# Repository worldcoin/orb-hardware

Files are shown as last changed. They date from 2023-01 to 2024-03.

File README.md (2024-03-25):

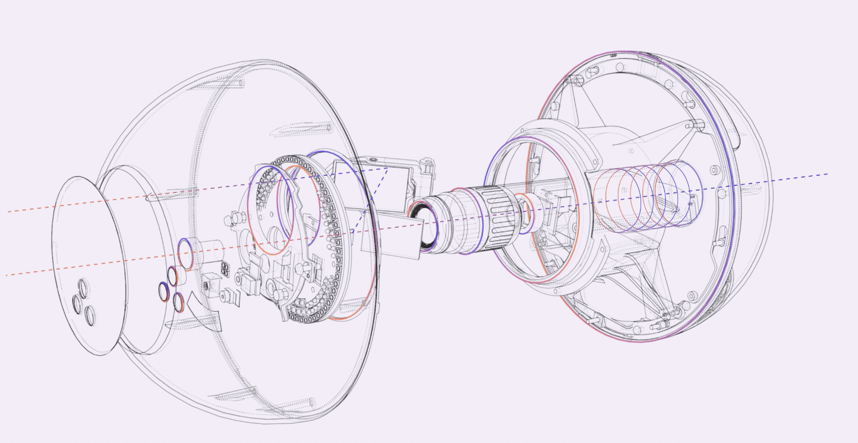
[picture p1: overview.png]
Overview


# Worldcoin Hardware

As we work towards decentralization, we are incrementally open sourcing the Orb. The goal is to provide transparency and, eventually, the ability to verify our claims. Ultimately, we plan to decentralize everything involving the Orb, enabling others to develop, manufacture, and operate similar devices to issue Proof-of-Personhood credentials in a privacy-preserving manner. 

We're excited to share the engineering files of the Orb with you! For more details on how it works in detail check out [our blogpost](https://worldcoin.org/blog/engineering/opening-orb-look-inside-worldcoin-biometric-imaging-device).

If you see any issues with the design, we encourage you to create an issue to help improve future versions. 

## High-level Goals

The goal of the hardware team at Tools for Humanity is to provide products that on a high level meet the following requirements:

* Validate humanness & create a unique code to verify uniqueness in a privacy-preserving manner, as seamlessly as possible
* Ready for mobile and outdoor use (think camera equipment)
* Continuous mobile use throughout the day without significant downtime
* Enable detection of internal attacks (physical manipulation of the device) and external fraud attempts (presentation attacks) by using additional sensors that are not needed for the calculation of the unique code
* Unique visual appearance

## Hardware Products

Our initial hardware product release consists of: 

* The Orb: our core imaging device
* A custom exchangeable battery for the Orb

We will expand the scope of this repository as new products mature. We expect privacy-preserving Proof-of-Personhood to become a lasting primitive for the internet.

## Directory Structure

    ├── Orb
    │   ├── Electronics
    │   ├── Mechanics
    |   └── BOM
    |
    ├── Battery
    |   ├── Electronics
    │   ├── Mechanics
    |   └── BOM

## What's not included

### Tamper detection system not disclosed 

For obvious reasons, these files do not include the PCBs and sensors related to the Orb's tamper detection system. 

### Components pending licenses for disclosure

When designing our product, we have utilized certain proprietary information (IP) that we have not yet received confirmation from the vendor to share, or that cannot be shared as part of our open-source efforts. This includes CAD models of certain electronic boards and IP related to the electrical interface between the Jetson and the heat camera. As a result, we are currently unable to publish the bridge board that connects the main board and the front unit.

## License

Copyright 2020-2023 The Worldcoin Foundation.

You may use this package under the Worldcoin Responsible Use License, version 1.0, or at your option, any later version. See the file [COPYING](COPYING.md) for more details, and [LICENSE](LICENSE.md) for the terms of the Worldcoin Responsible Use License, version 1.0.

The Worldcoin Responsible Use License seeks a balance between fostering transparency and decentralization while preventing capture (inspired by Uniswaps [BSL](https://uniswapfoundation.mirror.xyz/lr8hUW5FFYWmvsm9ZmO6bLdLAaAx5EAnFEbJG_OTd8g) and Electric Coin Co.’s [BOSL](https://electriccoin.co/blog/introducing-tgppl-a-radically-new-type-of-open-source-license/)) and reducing the risk that Worldcoin technology could be used in harmful ways. Under the license, within about two years of publication the Worldcoin Foundation will - consistent with its governance protocols and practices at the time - review and decide whether to remove the use restrictions specified in Section II.1 of the license. Further, no more than two years after that review date, those restrictions will be lifted. As this is an unfamiliar license you may have questions or feedback. Any proposals for improvements, objections or alternative approaches are welcome.

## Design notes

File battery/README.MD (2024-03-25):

## Overview
Our exchangeable battery is responsible for powering the orb during the dayli operations. Key facts: 
* **Cell**: 8x 18650 Li-Ion cells 
* **Configuration**: 4SP2 (4 in series, 2 strings parallel)
* **Nominal voltage**: 14.8V
* **Capacity**: 96.48Wh
* **Charging interface**: USB-C
* **Other**: UN38.3 certified

## Mechanics

You can download the .stp-files [here](mechanics/download.sh).

Preview STP-File:
<p align="center">
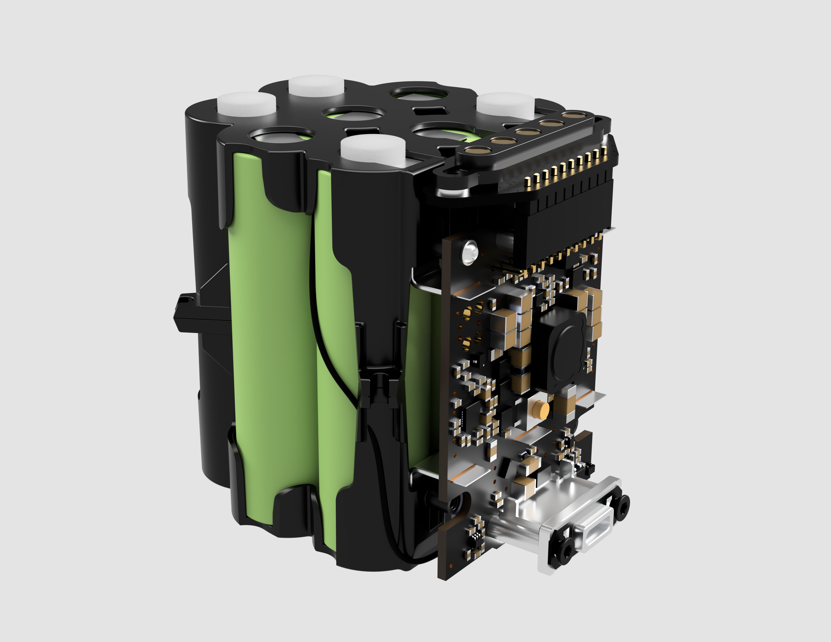
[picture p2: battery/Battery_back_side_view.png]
    
</p>

## Electronics

Preview battery circuit board:

<p align="center">
    
</p>

## Bill of material structure
Part of our release is a drilled-down bill of material listing all the parts used in our device. 

The columns in that file are: 
* **Level**: Due to multiple assemblies in our device, we have a nested BOM. The level column tells you how deep this component is nested.
* **Item number**: Running number within the Assembly / Sub-Assembly
* **Partnumber**: Our internal part-number
* **Manufacturer P/N**: The part-number / unique name that our supplier uses as a part reference
* **Quantity**: Quantity of the part in the given assembly context

Please note that some parts have multiple entries in our BOM as each line lists the component in a different assembly context. 

## Directory Structure

    ├── Electronics         # Board and schematics
    ├── Mechanics           # STP-Files
    └── BOM                 # Bill of material   

## License

Copyright 2020-2023 The Worldcoin Foundation.

You may use this package under the Worldcoin Responsible Use License, version 1.0, or at your option, any later version. See the file [COPYING](../COPYING.md) for more details, and [LICENSE](../LICENSE.md) for the terms of the Worldcoin Responsible Use License, version 1.0.

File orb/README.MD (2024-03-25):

## Overview
The orb consists of five modules that group our used components: 
* **Optics**: Passive optical parts (e.g., mirrors and lenses)
* **Cooling**: Passive cooling components (e.g., heat pipes)
* **Chassis**: Parts that form the internal structure
* **Outer shell**: Parts associated with the outer shell
* **Electronics**: PCBAs and other active electronic modules

If you look at our engineering data, you might find a difference between the renders of our device and the actual design. The reason is that the first design that we've put into manufacturing optimizes for precisely that. Ensure a fast time to market with an MVP and work on the final design after you have something that is manufacturable. 

## Required Tools
**Electronics**: The first release will only be EAGLE files. Later releases might be Altium. There are free viewers available for both. 

**Mechanics**: As we're releasing STP-Files, most standard CAD software should be able to open our models. If there are issues, please let us know.

## Mechanics

You can download the .stp-files [here](mechanics/download.sh).

Preview STP-File:

<p align="center">
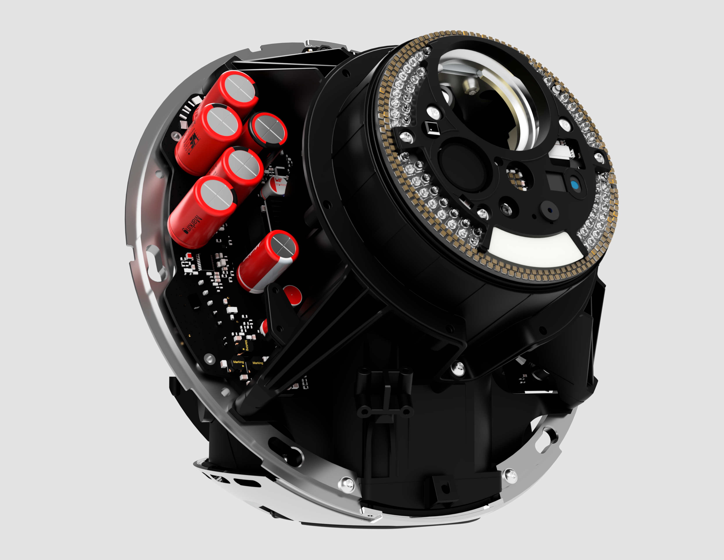
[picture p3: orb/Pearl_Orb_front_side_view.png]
    
</p>

## Electronics
Block diagram electronics: 

<p align="center">
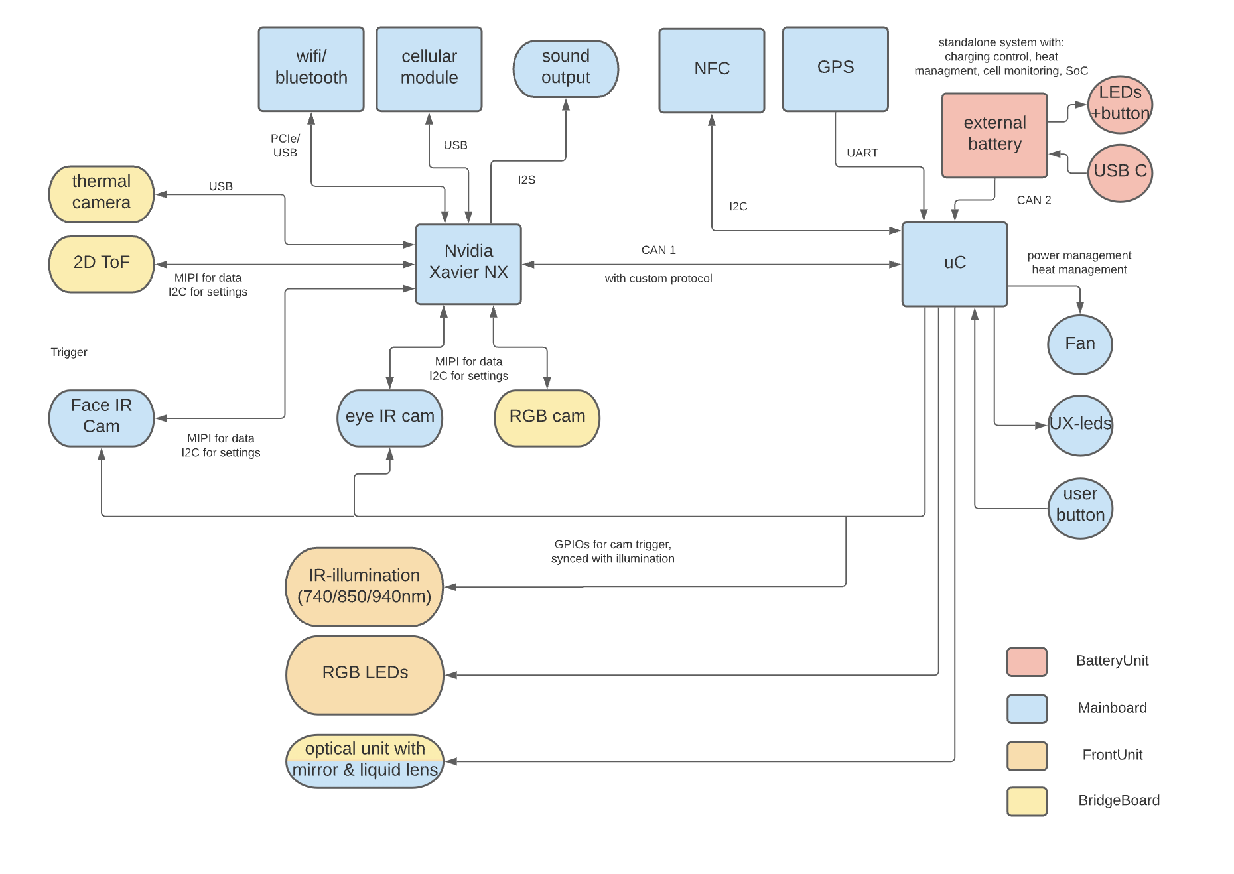
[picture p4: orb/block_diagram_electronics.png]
    
</p>

Preview Mainboard:

<p align="center">
    
</p>

Preview Frontunit:

<p align="center">
    
</p>

## Bill of material structure
Part of our release is a drilled-down bill of material listing all the parts used in our device. 

The columns in that file are: 
* **Level**: Due to multiple assemblies in our device, we have a nested BOM. The level column tells you how deep this component is nested. E.g. *TLA, PEARL ORB, EVT* is the top-level assembly and because of that level 0, the *Gimbal Inner Axis* is for example level 4 (*TLA, PEARL ORB, EVT* -> *Optics Module* -> *OCS Front Frame* -> *Gimbal Unit*)
* **Item number**: Running number within the Assembly / Sub-Assembly
* **Partnumber**: Our internal part-number
* **Manufacturer P/N**: The part-number / unique name that our supplier uses as a part reference
* **Quantity**: Quantity of the part in the given assembly context

Please note that some parts have multiple entries in our BOM as each line lists the component in a different assembly context. 

## Directory Structure

    ├── Electronics         # Board and schematics
    ├── Mechanics           # STP-Files
    └── BOM                 # Bill of material   

## License

Copyright 2020-2023 The Worldcoin Foundation.

You may use this package under the Worldcoin Responsible Use License, version 1.0, or at your option, any later version. See the file [COPYING](../COPYING.md) for more details, and [LICENSE](../LICENSE.md) for the terms of the Worldcoin Responsible Use License, version 1.0.

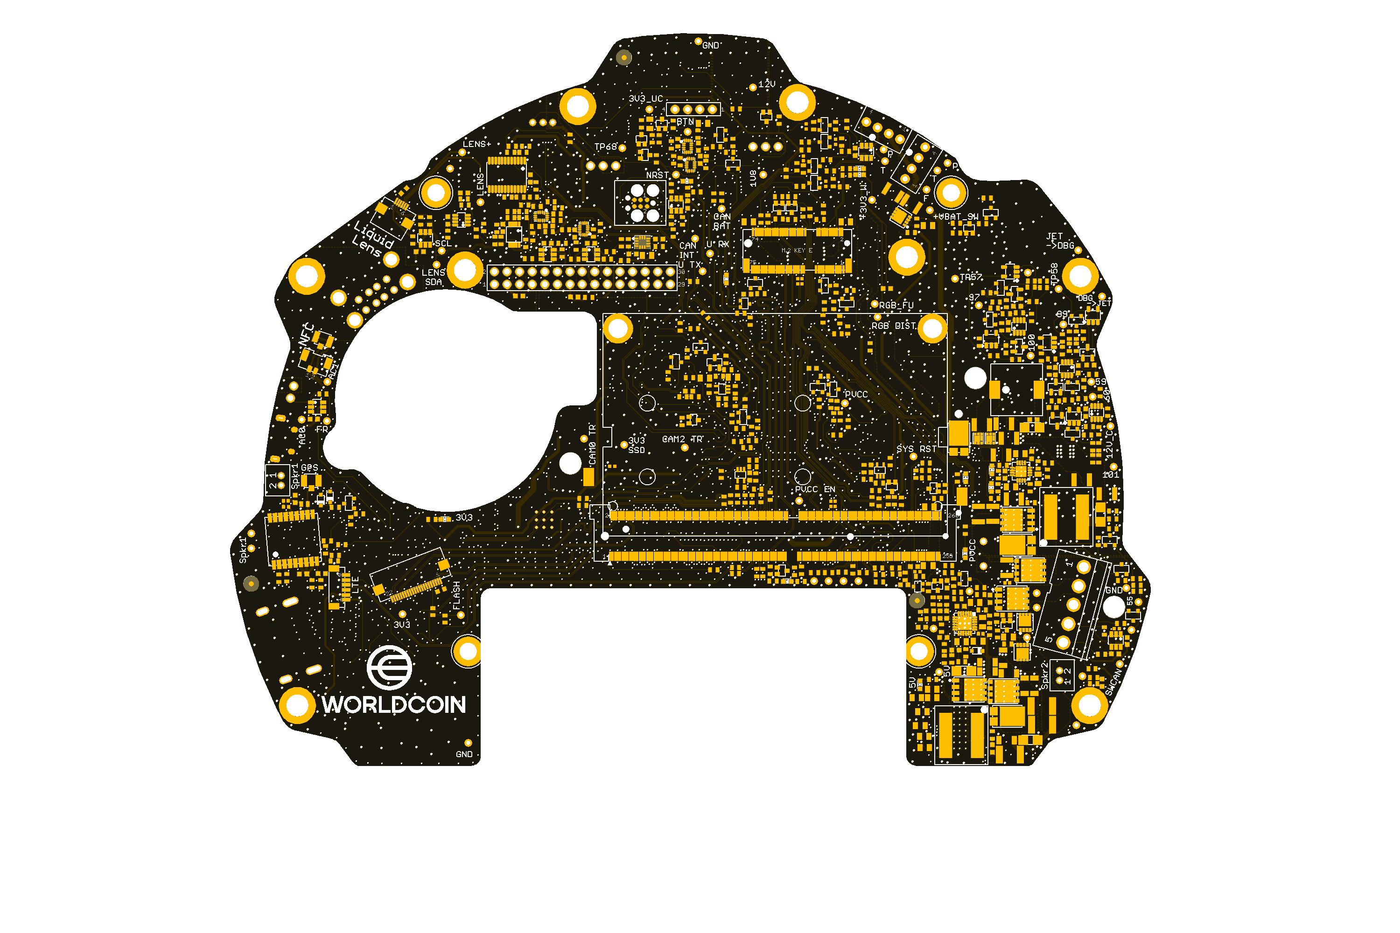
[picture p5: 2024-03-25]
orb/Preview_Mainboard_Top.png

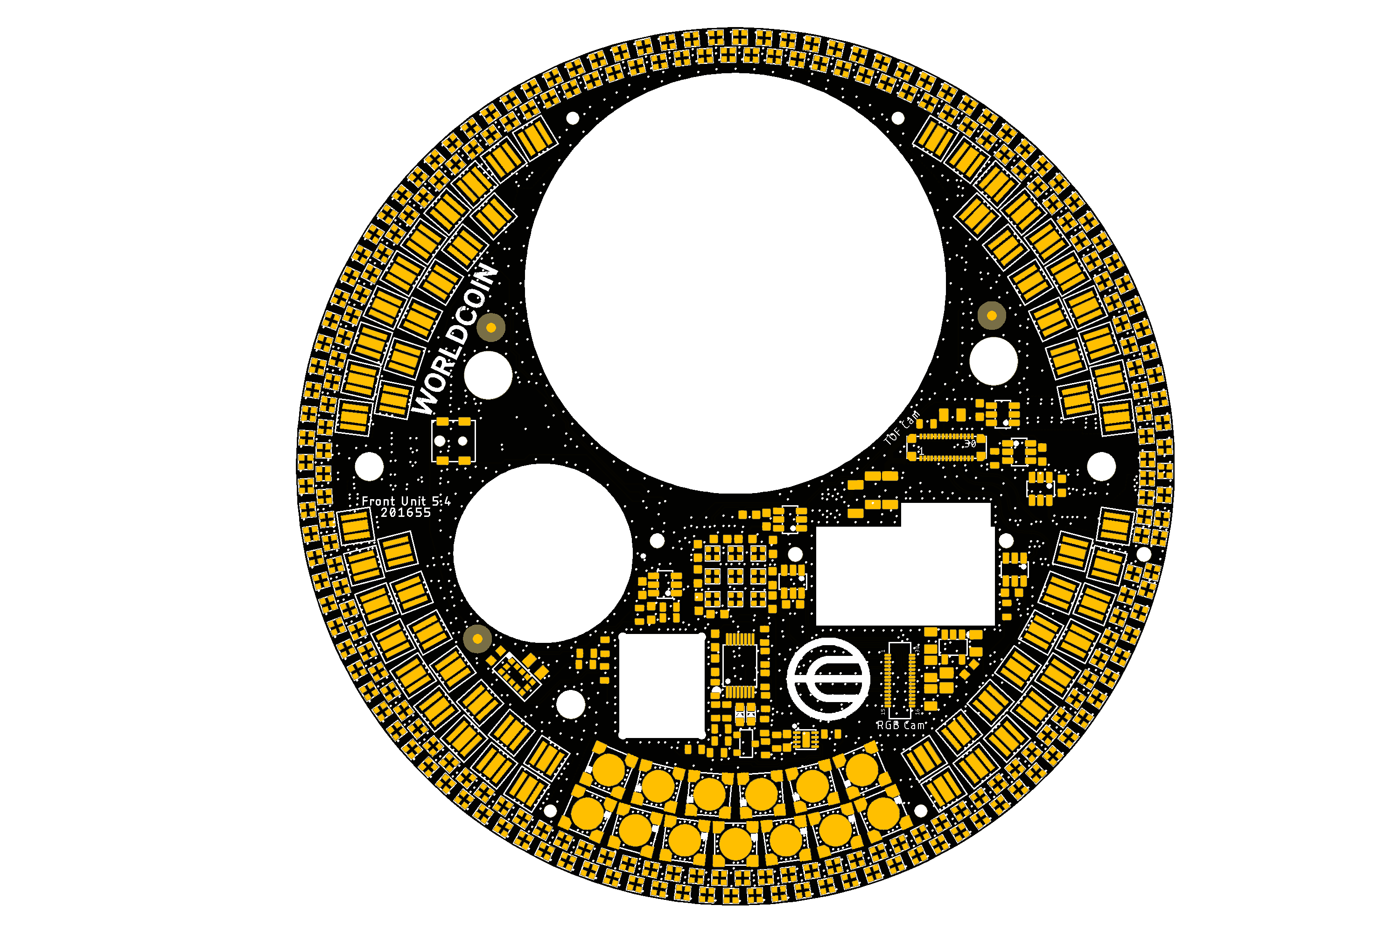
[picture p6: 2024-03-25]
orb/Preview_Frontunit_Top.png

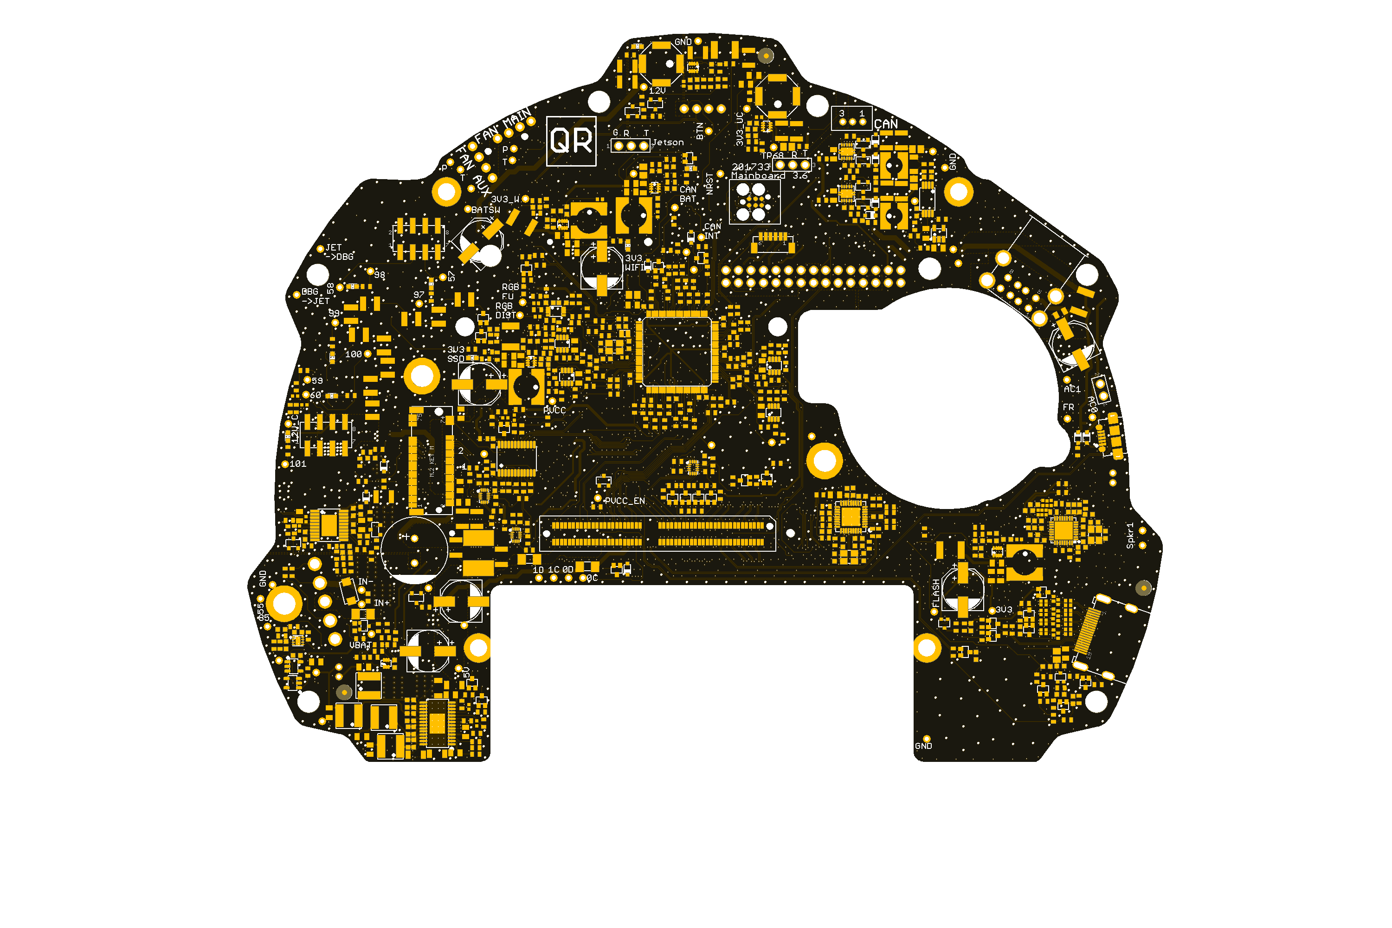
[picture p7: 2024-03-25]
orb/Preview_Mainboard_Bot.png

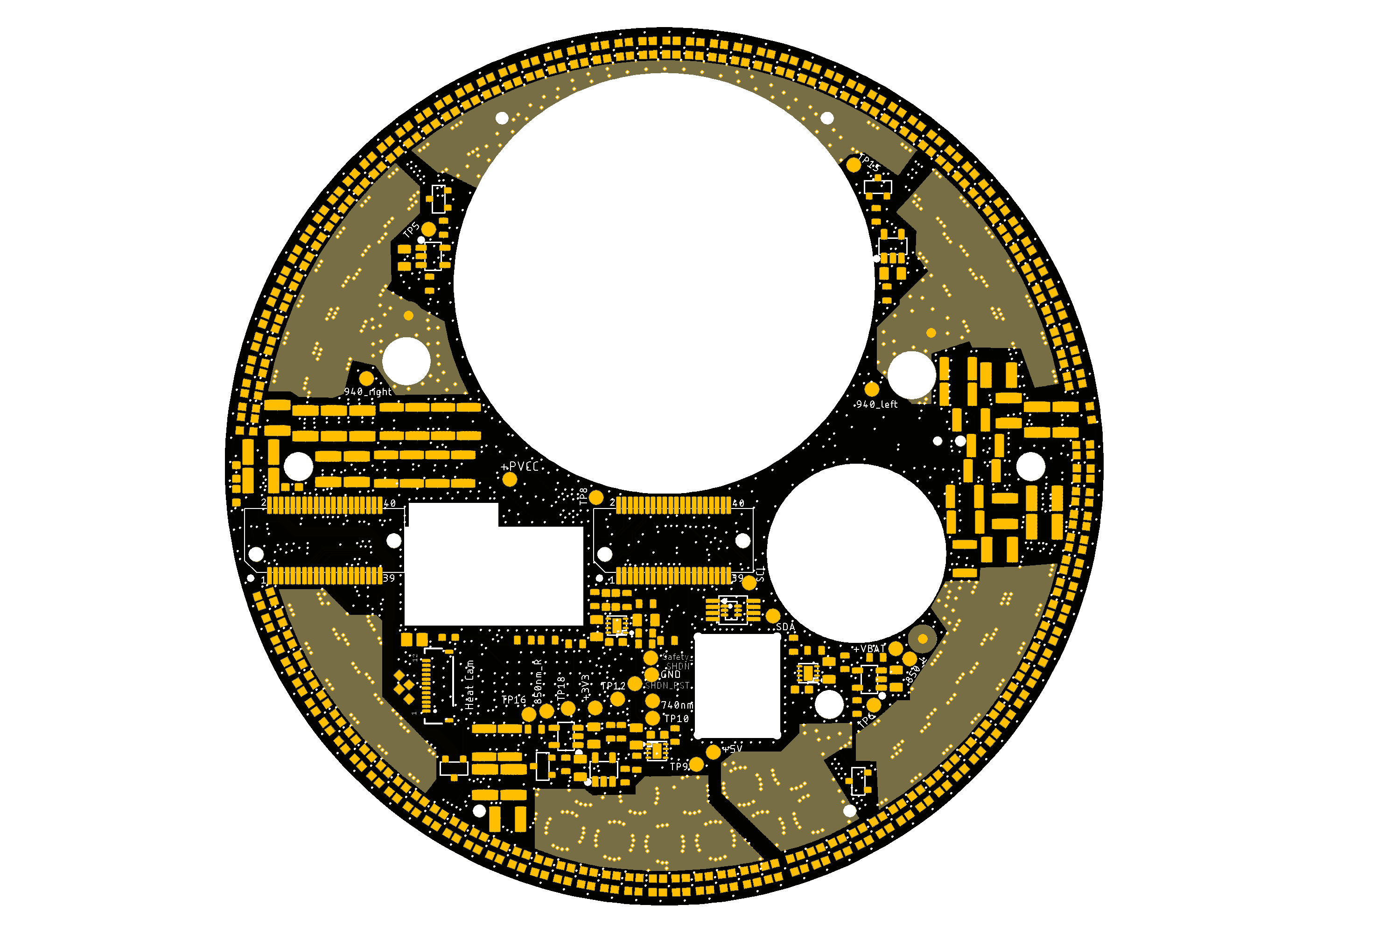
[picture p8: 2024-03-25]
orb/Preview_Frontunit_Bot.png

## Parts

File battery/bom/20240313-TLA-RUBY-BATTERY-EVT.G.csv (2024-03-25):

Level | Item Number | Partnumber | Manufacturer P/N | Quantity
0 | 1 | 84-00008 | TLA, RUBY BATTERY, EVT | 1
1 | 1 | 65-00031 | Li-Ion 18650 Cell | 8
1 | 2 | 71-00075 | Battery Case | 1
1 | 3 | 71-00086 | Battery Cap - dotted SoC | 1
1 | 4 | 71-00077 | Battery Cell Cage | 2
1 | 5 | 71-00078 | Battery Pushbutton | 1
1 | 6 | 73-00002 | Safety-Sticker | 1
1 | 7 | 73-00003 | Label Sticker, Ruby Battery | 1
1 | 8 | 73-00007 | M71-16-423 | 1
1 | 9 | 73-00016 | PRT_M71-16-423_IECcertInfo.1.0.A | 1
1 | 10 | 74-00048 | STP38A0200060S | 2
1 | 11 | 74-00073 | STP380250300S | 4
1 | 12 | 74-00088 | ISO14581-M2,5x6-steel8.8-black-T8 | 4
1 | 13 | 75-00052 | 0X-RDF1361 | 2
1 | 14 | 75-00053 | KS 1153 | 9
1 | 15 | 75-00060 | Kapton band width:50mm | 46.0
1 | 16 | 76-00018 | Battery Foot Front | 1
1 | 17 | 76-00019 | Battery Foot Back | 1
1 | 18 | 76-00020 | O-Ring 4x1, NBR 70 | 1
1 | 19 | 76-00024 | O-Ring 80x1.25 , NBR 70 | 1
1 | 20 | 76-00044 | Silicone Tube Piece 4,0x0,5mm 1090080405 | 15.0
1 | 21 | 81-00028 | PCBA-Battery_PCB | 1
2 | 1 | 61-00843 | C0603-100n-50V-20%-X7R | 44
2 | 2 | 61-00620 | C0603-100p-50V-10%-X7R | 7
2 | 3 | 61-00845 | C0805-4u7-16V-20%-X7R | 1
2 | 4 | 61-00895 | C0603-4n7-50V-20%-X7R | 2
2 | 5 | 61-00846 | C1210-4u7-50V-20%-X7R | 16
2 | 6 | 61-00844 | C0805-22u-10V-20%-X7T | 7
2 | 7 | 61-00848 | C0805-1u-25V-20%-X7R | 2
2 | 8 | 61-00608 | C0603-27p-50V-20%-C0G | 2
2 | 9 | 61-00263 | SMA6J20A-TR | 2
2 | 10 | 61-00197 | PMEG6010CEJ,115 | 6
2 | 11 | 61-00170 | 150060GS75000 | 1
2 | 12 | 61-00333 | 0680L9100-05 | 1
2 | 13 | 61-00339 | SFJ-1412 | 1
2 | 14 | 61-00336 | BQ294703DSGR | 1
2 | 15 | 61-00109 | SN74LV1T34DCKR | 1
2 | 16 | 61-00448 | SK6805-EC15 | 4
2 | 17 | 61-00458 | TMP112NAIDRLR | 1
2 | 18 | 61-00150 | 824001 | 2
2 | 19 | 61-00341 | STM32G431CBU6 | 1
2 | 20 | 61-00022 | TPS70933DRVR | 1
2 | 21 | 61-00006 | BQ24780SRUYR | 1
2 | 22 | 61-00779 | AP7387-50W5-7 | 1
2 | 23 | 61-00337 | BQ769X2PFB | 1
2 | 24 | 61-00002 | 744771004 | 1
2 | 25 | 61-00001 | 742792410 | 1
2 | 26 | 61-00335 | PRF15BE103RB6RC | 1
2 | 27 | 61-00106 | TSX-3225 24.0000MF10Z-C | 1
2 | 28 | 61-00499 | ECS-.327-12.5-12R-TR | 1
2 | 29 | 61-00651 | R0603-100k-63mW-1%-400ppm-50V | 16
2 | 30 | 61-00652 | R0603-10k-63mW-1%-400ppm-50V | 13
2 | 31 | 61-00653 | R0603-10R-63mW-1%-400ppm-50V | 52
2 | 32 | 61-00599 | R0603-0R-63mW-1%-400ppm-50V | 16
2 | 33 | 61-00026 | LVT12R0050FER | 3
2 | 34 | 61-00650 | R0603-1k-63mW-1%-400ppm-50V | 10
2 | 35 | 61-00683 | R0603-10Meg-63mW-1%-400ppm-50V | 11
2 | 36 | 61-00674 | R0603-510k-63mW-1%-400ppm-50V | 8
2 | 37 | 61-00686 | R0603-150R-63mW-1%-400ppm-50V | 4
2 | 38 | 61-00671 | R0603-330R-63mW-1%-400ppm-50V | 4
2 | 39 | 61-00797 | 430451035836 | 1
2 | 40 | 61-00334 | SiSS06DN-T1-GE3 | 4
2 | 41 | 61-00115 | DMG1012UW-7 | 9
2 | 42 | 61-00252 | PMF170XP,115 | 1
2 | 43 | 61-00024 | CSD17577Q3A | 1
2 | 44 | 61-00008 | CSD17308Q3 | 1
2 | 45 | 61-00198 | PMV30ENEAR | 5
2 | 46 | 61-00011 | MUSBR-M5C1-M0 | 1
2 | 47 | 62-00020 | 665102131822 | 2
2 | 48 | 61-00890 | 62002021121 | 1
2 | 49 | 63-00013 | PCB (UNPOPULATED), BMS ORB BATTERY | 1
1 | 22 | 81-00040 | Power_Connector_Battery_Side | 1
2 | 1 | 61-00889 | 62132021821 | 1
2 | 2 | 62-00066 | YJ-FDC25008-00 | 1
2 | 3 | 63-00042 | PCB (UNPOPULATED), POWER CONNECTOR BATTERY SIDE PCB | 1
1 | 23 | 83-00017 | Battery temperature sensor assembly | 2
2 | 1 | 61-00317 | NTCLE317E4103SBA | 1
2 | 2 | 61-00728 | Heat shrinking tube | 15.0
2 | 3 | 62-00033 | 665002113322 Female Housing | 1
2 | 4 | 62-00042 | 66500113722 | 2
2 | 5 | 61-00720 | Black Wire, TPC, 28 AWG, 0,70mm +/- 0,05mm, max. 216,00 Ohm/km at 20°C | 75.0
1 | 24 | 83-00022 | Hiluminstrip_long | 5
2 | 1 | 61-00727 | Hilumin strip | 65.0
1 | 25 | 83-00023 | Hiluminstrip_short | 6
2 | 1 | 61-00727 | Hilumin strip | 25.0
1 | 26 | 83-00024 | Heat shrinking tube - Hilumin | 5
2 | 1 | 61-00726 | Heat shrinking tube | 55.0

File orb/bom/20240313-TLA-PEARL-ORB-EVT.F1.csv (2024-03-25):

Level | Item Number | Partnumber | Manufacturer P/N | Quantity
0 | 1 | 84-00005 | TLA, PEARL ORB, EVT | 1
1 | 1 | 83-00009 | ASM, OPTICS MODULE, PEARL ORB | 1
2 | 1 | 71-00049 | OCS Enclosure | 1
2 | 2 | 71-00052 | OCS IR Separator | 1
2 | 3 | 71-00055 | Bridge PCB Clamp | 1
2 | 4 | 71-00074 | Heat pipe sealing clamp | 1
2 | 5 | 71-00097 | OCS Diffusor | 1
2 | 6 | 72-00028 | Optotune Lens Mount | 1
2 | 7 | 74-00052 | Screw, WN 1451/KN 1038, K30(3)x12, T10 | 16
2 | 8 | 74-00053 | Screw, ISO14583, M3(3)x8, T10 | 2
2 | 9 | 74-00057 | Screw, ISO14583, M2(2)x5, T6 | 5
2 | 10 | 74-00058 | Screw, KN6038, 2.5x25, T8 | 3
2 | 11 | 75-00010 | OMS-M2333PG-4-C, 23 x 33mm, PROTECTED GOLD, LAMBDA/4 | 1
2 | 12 | 75-00015 | E3390H | 1
2 | 13 | 76-00006 | O-Ring 95x1 clear | 2
2 | 14 | 76-00008 | O-Ring 25x1,5 | 2
2 | 15 | 76-00011 | O-Ring 4x1,5 | 2
2 | 16 | 76-00029 | IR Separator Foam Ring Gimbal | 1
2 | 17 | 76-00030 | IR Separator Foam Ring 2D ToF | 1
2 | 18 | 79-00005 | 3M™ Adhesive Transfer Tape 9473PC | 1
2 | 19 | 79-00008 | Delo Dualbond OB787 | 1
2 | 20 | 79-00009 | Adhesive Transfer Tape IR Separator Diffusor | 1
2 | 21 | 83-00014 | OCS Front Frame | 1
3 | 1 | 72-00024 | OCS Front Frame Disc | 1
3 | 2 | 72-00025 | IR Lens Mount | 1
3 | 3 | 72-00046 | Front Heat Pipe Clamp | 1
3 | 4 | 72-00049 | Heat Pipe OCS Frame | 1
3 | 5 | 74-00053 | Screw, ISO14583, M3(3)x8, T10 | 6
3 | 6 | 76-00026 | Gap filler pad heat camera | 1
3 | 7 | 76-00027 | Gap filler pad 2D ToF | 1
3 | 8 | 76-00035 | Gap filler pad Front Unit 1 | 1
3 | 9 | 76-00036 | Gap filler pad Front Unit 2 | 1
3 | 10 | 76-00037 | Gap filler pad Front Unit 3 | 1
3 | 11 | 76-00038 | Gap filler pad Front Unit 4 | 1
3 | 12 | 76-00039 | Gap filler pad Front Unit 5 | 1
3 | 13 | 83-00015 | Gimbal Unit | 1
4 | 1 | 71-00050 | Gimbal Inner Axis | 1
4 | 2 | 71-00057 | Gimbal Bearing Holder | 3
4 | 3 | 72-00026 | Gimbal Frame | 1
4 | 4 | 72-00047 | Gimbal Frame Heat Pipe Clamp | 1
4 | 5 | 72-00048 | Heat Pipe Gimbal Frame | 1
4 | 6 | 72-00058 | Gimbal Pin | 1
4 | 7 | 74-00055 | MF 85 2Z | 4
4 | 8 | 74-00056 | Screw, WN 1451/KN 1038, 2x6, T6 | 7
4 | 9 | 74-00057 | Screw, ISO14583, M2(2)x5, T6 | 1
4 | 10 | 74-00071 | Screw, ISO 14580, M3(3)x6, TX10 | 2
4 | 11 | 83-00016 | Mirror Unit | 1
5 | 1 | 71-00051 | Mirror Holder | 1
5 | 2 | 75-00011 | OMS-M2540PG-4-C, 27 x 42mm, PROTECTED GOLD, LAMBDA/4 | 1
5 | 3 | 79-00005 | 3M™ Adhesive Transfer Tape 9473PC | 1
2 | 22 | 83-00030 | Printed on Curved Face | 1
3 | 1 | 83-00035 | Curved face assembly (glued) | 1
4 | 1 | 71-00094 | LED light guide inclusive light blocker (Jabil) | 1
4 | 2 | 71-00085 | UX LED Cover | 1
4 | 3 | 77-00001 | Curved Face | 1
4 | 4 | 77-00002 | RGB Cover | 1
4 | 5 | 77-00003 | Heat Cover, Germanium, both sides coated to meet T_avg>85% for 7,8-14μm | 1
4 | 6 | 79-00002 | 30cc Kartusche DELO DUALBOND GE4910 (Hersteller = DELO) | 1
1 | 2 | 83-00010 | ASM, COOLING MODULE, PEARL ORB | 1
2 | 1 | 71-00059 | Cooling Air Intake | 1
2 | 2 | 71-00060 | Cooling Air Outlet | 1
2 | 3 | 72-00030 | Cooling Adapter Jetson Xavier | 1
2 | 4 | 72-00044 | Heat Sink | 1
2 | 5 | 72-00045 | OCS Heat Pipe Clamp | 1
2 | 6 | 72-00057 | Heat Sink SSD | 1
2 | 7 | 74-00052 | Screw, WN 1451/KN 1038, K30(3)x12, T10 | 5
2 | 8 | 74-00053 | Screw, ISO14583, M3(3)x8, T10 | 6
2 | 9 | 74-00058 | Screw, KN6038, 2.5x25, T8 | 2
2 | 10 | 74-00083 | shoulder screw Nvidia Jetson Xavier | 4
2 | 11 | 75-00065 | Leaf spring Nvidia Jetson Xavier | 1
2 | 12 | 76-00012 | Gap filler pad GEL 60 10 - 10mm x 13mm x 1mm | 4
2 | 13 | 76-00014 | Gap filler pad GEL 60 10 - 16mm x 21mm x 1mm | 1
2 | 14 | 76-00015 | Gap Filler SSD | 1
2 | 15 | 76-00032 | O-Ring 14,0 x 2,0 mm EPDM70+/- 5 Shore A black | 2
2 | 16 | 76-00034 | Gap filler pad Heatsink | 1
1 | 3 | 83-00011 | ASM, CHASSIS, PEARL ORB | 1
2 | 1 | 71-00037 | Frame Bottom | 1
2 | 2 | 71-00038 | Battery Holder | 1
2 | 3 | 71-00043 | Shell Light Guide Mount | 1
2 | 4 | 71-00047 | Shell Operator Button | 1
2 | 6 | 71-00099 | Blade connector adapter | 1
2 | 7 | 71-00100 | Wifi Clip | 1
2 | 8 | 72-00022 | Frame Aluminium Ring | 1
2 | 10 | 74-00070 | DIN 965 TX A2 M2,5X8 BLACK | 2
2 | 11 | 74-00052 | Screw, WN 1451/KN 1038, K30(3)x12, T10 | 13
2 | 12 | 74-00053 | Screw, ISO14583, M3(3)x8, T10 | 5
2 | 13 | 74-00056 | Screw, WN 1451/KN 1038, 2x6, T6 | 10
2 | 14 | 74-00057 | Screw, ISO14583, M2(2)x5, T6 | 3
2 | 15 | 76-00040 | Foam battery bumper | 1
1 | 4 | 83-00012 | ASM, ELECTRONICS MODULE, PEARL ORB | 1
2 | 1 | 81-00013 | PCBA, BRIDGE BOARD, PEARL ORB | 1
3 | 1 | 61-00599 | R0603-0R-63mW-1%-400ppm-50V | 20
3 | 2 | 61-00651 | R0603-100k-63mW-1%-400ppm-50V | 12
3 | 3 | 61-00609 | C0603-100n-50V-20%-X5R | 18
3 | 4 | 61-00620 | C0603-100p-50V-10%-X7R | 9
3 | 5 | 61-00653 | R0603-10R-63mW-1%-400ppm-50V | 4
3 | 6 | 61-00652 | R0603-10k-63mW-1%-400ppm-50V | 8
3 | 7 | 61-00693 | R0603-10k-63mW-0%1-50ppm-50V | 1
3 | 8 | 61-00655 | R0603-12k-63mW-1%-400ppm-50V | 2
3 | 9 | 61-00170 | 150060GS75000 | 3
3 | 10 | 61-00708 | R1206-1R-250mW-1%-400ppm-200V | 4
3 | 11 | 61-00598 | C0603-1uF-25V-20%-X5R | 4
3 | 12 | 61-00625 | C0805-22u-10V-20%-X5R | 6
3 | 13 | 61-00689 | R0603-27k-63mW-1%-400ppm-50V | 4
3 | 14 | 61-00608 | C0603-27p-50V-20%-C0G | 3
3 | 15 | 61-00612 | C0603-33n-50V-10%-X7R | 3
3 | 16 | 61-00688 | R0603-3k-63mW-1%-400ppm-50V | 1
3 | 17 | 61-00672 | R0603-442k-63mW-1%-400ppm-50V | 1
3 | 18 | 61-00705 | R0603-47k-63mW-0%1-50ppm-50V | 3
3 | 19 | 61-00629 | C1210-4u7-50V-20%-X5R | 3
3 | 20 | 61-00445 | 653104124022 | 2
3 | 21 | 61-00164 | 687122149022 | 1
3 | 22 | 61-00092 | 742792097 | 4
3 | 23 | 61-00087 | 74402500047 | 1
3 | 24 | 61-00493 | 744029001 | 2
3 | 25 | 61-00150 | 824001 | 1
3 | 26 | 61-00083 | 865060553007 | 1
3 | 27 | 61-00167 | 875115150005 | 1
3 | 28 | 61-00359 | 9774070243R | 1
3 | 29 | 61-00115 | DMG1012UW-7 | 2
3 | 30 | 61-00192 | LM393BIDSGR | 1
3 | 31 | 61-00369 | LPC4330FET100,551 | 1
3 | 32 | 61-00197 | PMEG6010CEJ,115 | 1
3 | 33 | 61-00370 | TMC5041-LA | 1
3 | 34 | 61-00216 | TMUX1209RSVR | 1
3 | 35 | 61-00590 | TPS62825ADMQR | 1
3 | 36 | 61-00438 | TPS62933DRLR | 2
3 | 37 | 61-00106 | TSX-3225 24.0000MF10Z-C | 1
3 | 38 | 61-00360 | W25Q32JVZPIQ | 1
3 | 39 | 63-00020 | PCB (UNPOPULATED), Bridge Board, EVT | 1
2 | 2 | 81-00014 | PCBA, MAINBOARD, PEARL ORB | 1
3 | 1 | 61-00599 | R0603-0R-63mW-1%-400ppm-50V | 79
3 | 2 | 61-00709 | R1206-0R15-250mW-1%-800ppm-200V | 1
3 | 3 | 61-00168 | 1-2199230-5 | 1
3 | 4 | 61-00651 | R0603-100k-63mW-1%-400ppm-50V | 112
3 | 5 | 61-00605 | C0402-100n-16V-20%-X5R | 12
3 | 6 | 61-00609 | C0603-100n-50V-20%-X5R | 101
3 | 7 | 61-00620 | C0603-100p-50V-10%-X7R | 2
3 | 8 | 61-00652 | R0603-10k-63mW-1%-400ppm-50V | 27
3 | 9 | 61-00693 | R0603-10k-63mW-0%1-50ppm-50V | 16
3 | 10 | 61-00616 | C0603-10n-50V-20%-X5R | 15
3 | 11 | 61-00610 | C0603-10p-50V-10%-X7R | 4
3 | 12 | 61-00628 | C1206-10u-50V-20%-X5R | 11
3 | 13 | 61-00655 | R0603-12k-63mW-1%-400ppm-50V | 2
3 | 14 | 61-00169 | 150060BS75000 | 2
3 | 15 | 61-00170 | 150060GS75000 | 18
3 | 16 | 61-00621 | C0603-150p-50V-10%-X7R | 2
3 | 17 | 61-00791 | R0603-18R-63mW-1%-400ppm-50V | 20
3 | 18 | 61-00657 | R0603-18k-63mW-1%-400ppm-50V | 23
3 | 19 | 61-00685 | R0603-1Meg-63mW-1%-400ppm-50V | 15
3 | 20 | 61-00650 | R0603-1k-63mW-1%-400ppm-50V | 13
3 | 21 | 61-00659 | R0603-1k8-63mW-1%-400ppm-50V | 25
3 | 22 | 61-00697 | R0603-1k8-63mW-0%1-50ppm-50V | 1
3 | 23 | 61-00598 | C0603-1uF-25V-20%-X5R | 1
3 | 24 | 61-00623 | C0805-1u-25V-20%-X5R | 23
3 | 25 | 61-00073 | 2199230-4 | 1
3 | 26 | 61-00606 | C0402-220p-25V-10%-X7R | 20
3 | 27 | 61-00625 | C0805-22u-10V-20%-X5R | 33
3 | 28 | 61-00191 | 2309413-1 | 1
3 | 29 | 61-00667 | R0603-27R-63mW-1%-400ppm-50V | 180
3 | 30 | 61-00689 | R0603-27k-63mW-1%-400ppm-50V | 1
3 | 31 | 61-00608 | C0603-27p-50V-20%-C0G | 14
3 | 32 | 61-00611 | C0603-2n2-50V-10%-X7R | 6
3 | 33 | 61-00622 | C0603-2u2-50V-20%-X5R | 7
3 | 34 | 61-00671 | R0603-330R-63mW-1%-400ppm-50V | 2
3 | 35 | 61-00687 | R0603-3R3-63mW-1%-400ppm-50V | 10
3 | 36 | 61-00719 | R1210-3R3-500mW-1%-100ppm-200V | 10
3 | 37 | 61-00738 | R0603-3k3-63mW-1%-400ppm-50V | 4
3 | 38 | 61-00684 | R0603-43k-63mW-1%-400ppm-50V | 7
3 | 39 | 61-00672 | R0603-442k-63mW-1%-400ppm-50V | 9
3 | 40 | 62-00036 | 470531000 | 2
3 | 41 | 61-00705 | R0603-47k-63mW-0%1-50ppm-50V | 11
3 | 42 | 61-00646 | R0402-499R-63mW-1%-400ppm-50V | 11
3 | 43 | 61-00636 | R0402-4R7-63mW-1%-400ppm-50V | 16
3 | 44 | 61-00624 | C0805-4u7-16V-20%-X5R | 8
3 | 45 | 61-00629 | C1210-4u7-50V-20%-X5R | 27
3 | 46 | 61-00891 | 5055680271 | 1
3 | 47 | 62-00063 | 61030821121 | 2
3 | 48 | 61-00154 | 61300211121 | 1
3 | 49 | 62-00037 | 61300411821 | 1
3 | 50 | 61-00155 | 61303021121 | 1
3 | 51 | 61-00156 | 61400826021 | 1
3 | 52 | 62-00011 | 62000211622 | 2
3 | 53 | 61-00159 | 629105150921 | 1
3 | 54 | 61-00160 | 636101111001 | 1
3 | 55 | 61-00161 | 645005114822 | 1
3 | 56 | 62-00039 | 665306124022 | 2
3 | 57 | 61-00069 | 685119134923 | 1
3 | 58 | 61-00163 | 687106149022 | 1
3 | 59 | 61-00164 | 687122149022 | 1
3 | 60 | 61-00092 | 742792097 | 6
3 | 61 | 61-00151 | 74279252 | 8
3 | 62 | 61-00879 | 7427928801 | 1
3 | 63 | 61-00157 | 74404054100 | 4
3 | 64 | 61-00152 | 744043220 | 2
3 | 65 | 61-00439 | 744062001 | 4
3 | 66 | 61-00488 | 744071039 | 2
3 | 67 | 61-00158 | 74439369033 | 2
3 | 68 | 61-00153 | 7447714068 | 1
3 | 69 | 61-00896 | 744917227 | 2
3 | 70 | 61-00150 | 824001 | 6
3 | 71 | 61-00873 | 830106246109 | 1
3 | 72 | 61-00166 | 860080678021 | 1
3 | 73 | 61-00083 | 865060553007 | 1
3 | 74 | 61-00444 | 875115252003 | 6
3 | 75 | 64-00002 | 9774025360R | 8
3 | 76 | 64-00006 | 9774060360R | 2
3 | 77 | 64-00003 | 9774065151R | 2
3 | 78 | 61-00099 | BAS70W-05-7-F | 2
3 | 79 | 61-00173 | BQ24640RVAR | 1
3 | 80 | 61-00185 | CSD15571Q2 | 2
3 | 81 | 61-00186 | CSD18504Q5A | 2
3 | 82 | 61-00187 | CSD18512Q5B | 3
3 | 83 | 61-00115 | DMG1012UW-7 | 32
3 | 84 | 61-00113 | DMP2006UFG-7 | 3
3 | 85 | 61-00499 | ECS-.327-12.5-12R-TR | 1
3 | 86 | 61-00188 | G639F100151102HR | 1
3 | 87 | 61-00189 | ICM-40627 | 1
3 | 88 | 61-00798 | INA180A1IDBVR | 1
3 | 89 | 61-00190 | INA240A1PW | 1
3 | 90 | 61-00443 | LM25117PSQ/NOPB | 1
3 | 91 | 61-00192 | LM393BIDSGR | 1
3 | 92 | 61-00193 | LM5122MH/NOPB | 1
3 | 93 | 61-00892 | LTC4316IMS#PBF | 1
3 | 94 | 61-00194 | LVT12R0030GER | 1
3 | 95 | 61-00026 | LVT12R0050FER | 1
3 | 96 | 61-00195 | LVT12R0100FER | 2
3 | 97 | 65-00004 | MAX-M8Q-0-10 | 1
3 | 98 | 61-00250 | NX7002AK,215 | 30
3 | 99 | 61-00196 | PMEG060V100EPDZ | 2
3 | 100 | 61-00812 | PMEG100V100ELPEZ | 1
3 | 101 | 61-00197 | PMEG6010CEJ,115 | 10
3 | 102 | 61-00252 | PMF170XP,115 | 5
3 | 103 | 61-00198 | PMV30ENEAR | 4
3 | 104 | 61-00800 | REF3020AIDBZR | 1
3 | 105 | 61-00103 | SF-1206SA1000W-2 | 3
3 | 106 | 61-00500 | SMA6J15CA | 1
3 | 107 | 61-00207 | SN74AXC8T245PWR | 1
3 | 108 | 61-00109 | SN74LV1T34DCKR | 3
3 | 109 | 61-00210 | SN74LVC2T45DCUR | 1
3 | 110 | 61-00872 | ST25R3918-AQWT | 1
3 | 111 | 61-00211 | STM32G474VET6 | 1
3 | 112 | 61-00212 | TAS5805MPWP | 1
3 | 113 | 61-00213 | TCR2LF18,LM | 1
3 | 114 | 61-00449 | TLV431IDBVR | 5
3 | 115 | 61-00215 | TLV9152IDDFR | 8
3 | 116 | 61-00458 | TMP112NAIDRLR | 1
3 | 117 | 61-00216 | TMUX1209RSVR | 6
3 | 118 | 61-00438 | TPS62933DRLR | 6
3 | 119 | 61-00106 | TSX-3225 24.0000MF10Z-C | 2
3 | 120 | 61-00218 | UCC27282DRCR | 2
3 | 121 | 61-00217 | USB2514B/M2 | 1
3 | 122 | 63-00022 | PCB (UNPOPULATED), MAINBOARD, EVT | 1
2 | 3 | 81-00038 | PCBA, SUPERCAP_BOARD, PEARL ORB | 1
3 | 1 | 61-00498 | 850617022001 | 5
3 | 2 | 61-00170 | 150060GS75000 | 1
3 | 3 | 61-00651 | R0603-100k-63mW-1%-400ppm-50V | 1
3 | 4 | 61-00883 | 9775036960R | 2
3 | 5 | 61-00882 | 610308243021 | 2
3 | 6 | 63-00040 | PCB(UNPOPULATED), Supercap_Board | 1
2 | 4 | 81-00015 | PCBA, FRONT UNIT, PEARL ORB | 1
3 | 1 | 61-00599 | R0603-0R-63mW-1%-400ppm-50V | 15
3 | 2 | 61-00649 | R0603-100R-63mW-1%-400ppm-50V | 1
3 | 3 | 61-00609 | C0603-100n-50V-20%-X5R | 18
3 | 4 | 61-00620 | C0603-100p-50V-10%-X7R | 1
3 | 5 | 61-00652 | R0603-10k-63mW-1%-400ppm-50V | 4
3 | 6 | 61-00170 | 150060GS75000 | 1
3 | 7 | 61-00079 | 150060RS75000-REV | 1
3 | 8 | 61-00792 | CRCW121015R0FKEAHP | 3
3 | 9 | 61-00658 | R0603-1k1-63mW-1%-400ppm-50V | 1
3 | 10 | 61-00598 | C0603-1uF-25V-20%-X5R | 113
3 | 11 | 61-00623 | C0805-1u-25V-20%-X5R | 9
3 | 12 | 61-00625 | C0805-22u-10V-20%-X5R | 5
3 | 13 | 61-00626 | C1206-22u-16V-20%-X5R | 2
3 | 14 | 61-00667 | R0603-27R-63mW-1%-400ppm-50V | 15
3 | 15 | 61-00689 | R0603-27k-63mW-1%-400ppm-50V | 1
3 | 16 | 61-00608 | C0603-27p-50V-20%-C0G | 1
3 | 17 | 61-00624 | C0805-4u7-16V-20%-X5R | 1
3 | 18 | 61-00629 | C1210-4u7-50V-20%-X5R | 18
3 | 19 | 61-00677 | R0603-56k-63mW-1%-400ppm-50V | 10
3 | 20 | 61-00900 | CRCW12105R60FKEAHP | 16
3 | 21 | 61-00457 | 687112182122 | 1
3 | 22 | 61-00092 | 742792097 | 2
3 | 23 | 61-00279 | 74279269 | 1
3 | 24 | 61-00150 | 824001 | 7
3 | 25 | 61-00704 | R0603-91k-63mW-1%-400ppm-50V | 1
3 | 26 | 61-00781 | ATE-1C-V-T/R | 1
3 | 27 | 61-00288 | AXE530127 | 1
3 | 28 | 61-00460 | BU27030NUC-E2 | 1
3 | 29 | 61-00290 | DF37NC-30DS-0.4V(51) | 1
3 | 30 | 61-00192 | LM393BIDSGR | 3
3 | 31 | 61-00313 | LZ1-00R302-0000 | 13
3 | 32 | 61-00282 | MEC6-120-02-L-DV-A | 2
3 | 33 | 61-00250 | NX7002AK,215 | 1
3 | 34 | 61-00198 | PMV30ENEAR | 5
3 | 35 | 61-00448 | SK6805-EC15 | 233
3 | 36 | 61-00292 | SN74LVC112ADGVR | 1
3 | 37 | 61-00314 | SST-10-IRD-B50-S940 | 32
3 | 38 | 61-00265 | SST-10-IRD-B50-T850 | 32
3 | 39 | 61-00880 | TLV71328PDBVR | 1
3 | 40 | 61-00458 | TMP112NAIDRLR | 1
3 | 41 | 61-00284 | UCC27517DBVT | 5
3 | 42 | 61-00269 | VL53L1CBV0FY/1 | 1
3 | 43 | 63-00021 | PCB (UNPOPULATED), FRONT UNIT, EVT | 1
2 | 5 | 82-00016 | ASM_PowerCon_To_645005113322 | 1
3 | 1 | 81-00039 | PCBA, POWER CONNECTOR ORB SIDE, PEARL ORB | 1
4 | 1 | 61-00372 | 9774010151R | 2
4 | 2 | 62-00067 | YJ-FDC25008-01 | 1
4 | 3 | 63-00041 | PCB (UNPOPULATED), POWER CONNECTOR ORB SIDE, EVT | 1
3 | 2 | 61-00722 | Wire, TPC, 18 AWG, 1,58mm +/- 0,05mm, max. 20,00 Ohm/km at 20°C | 465.0
3 | 3 | 61-00504 | 64500113722 | 3
3 | 4 | 62-00026 | 645005113322 | 1
2 | 8 | 81-00023 | PCBA, OPERATOR BUTTON, PEARL ORB | 1
3 | 1 | 61-00599 | R0603-0R-63mW-1%-400ppm-50V | 1
3 | 2 | 61-00625 | C0805-22u-10V-20%-X5R | 2
3 | 3 | 61-00667 | R0603-27R-63mW-1%-400ppm-50V | 2
3 | 4 | 61-00270 | 430451025836 | 1
3 | 5 | 62-00043 | 61300411021 | 1
3 | 6 | 61-00448 | SK6805-EC15 | 5
3 | 7 | 63-00016 | PCB (UNPOPULATED), OPERATOR BUTTON | 1
2 | 10 | 61-00149 | 6,00 MTP | 1
2 | 11 | 65-00038 | WDS250G3B0C | 1
2 | 12 | 65-00003 | VK000434 | 2
2 | 13 | 81-00041 | Flashed Jetson Xavier NX Module 16GB | 1
3 | 1 | 65-00035 | Jetson Xavier NX Module, 16GB | 1
3 | 2 | 99-00001 | OS Software | 1
2 | 14 | 65-00014 | AX200.NGWG.NV | 1
2 | 15 | 65-00040 | IMX219-D120 (40cm) | 1
2 | 16 | 75-00006 | LIQUID LENS, EL-12-30, OPTOTUNE | 1
2 | 17 | 75-00016 | MS201S | 1
2 | 18 | 75-00019 | 2065600300 | 1
2 | 19 | 75-00035 | VSM1069B | 2
2 | 20 | 75-00059 | 1461531250 | 1
2 | 21 | 61-00454 | 687622100002 | 1
2 | 22 | 61-00455 | 687622050002 | 1
2 | 23 | 65-00042 | Everflow R124028BU 3 blade | 1
2 | 24 | 82-00006 | ASM Speaker ND16FA-6 | 2
3 | 1 | 65-00011 | ND16FA-6 | 1
3 | 2 | 62-00024 | 620002113322 | 1
3 | 3 | 62-00046 | 62000113722 | 2
3 | 4 | 61-00725 | Wire, TPC, 24 AWG, 0,92mm +/- 0,05mm, max. 88,00 Ohm/km at 20°C | 180.0
2 | 27 | 82-00015 | ASM_NFC_Ant_To_505565-0201 | 1
3 | 1 | 65-00048 | 1462360101 | 1
3 | 2 | 62-00068 | 505565-0201 | 1
3 | 3 | 62-00069 | 505431-1000 | 2
3 | 4 | 61-00720 | Black Wire, TPC, 28 AWG, 0,70mm +/- 0,05mm, max. 216,00 Ohm/km at 20°C | 250.0
3 | 5 | 61-00897 | Red Wire, TPC, 28 AWG, 0,70mm +/- 0,05mm, max. 216,00 Ohm/km at 20°C | 250.0
2 | 28 | 74-00061 | Screw, ISO14579, M2.5(2.5)x5, T8 | 2
2 | 29 | 74-00053 | Screw, ISO14583, M3(3)x8, T10 | 6
1 | 5 | 83-00013 | ASM, OUTER SHELL, PEARL ORB | 1
2 | 1 | 71-00039 | Shell Chrome Back | 1
2 | 2 | 71-00041 | Shell Chrome Front | 1
2 | 3 | 71-00042 | Shell Light Pipe | 1
2 | 4 | 71-00044 | Shell Clear Back | 1
2 | 5 | 71-00045 | Shell Clear Front | 1
2 | 6 | 71-00048 | Shell Spacer | 6
2 | 7 | 72-00023 | Frame Retaining Ring | 1
2 | 8 | 73-00001 | Tamper Stick Label size: 0.75” (19.05 mm) x 2.0” (50.8 mm) | 1
2 | 9 | 74-00052 | Screw, WN 1451/KN 1038, K30(3)x12, T10 | 17
2 | 10 | 74-00075 | Screw, KN6041, 1.8x10, T6 | 2
2 | 11 | 83-00028 | Laser engraved Shell Chrom Bottom | 1
3 | 1 | 71-00046 | Shell Chrom Bottom | 1
2 | 12 | 83-00034 | Printed on Shell Antenna Cover | 1
3 | 1 | 71-00095 | Antenne Cover ABS Vampsab 0023 V0 DF | 1
1 | 6 | 83-00033 | Pouch cell battery kit | 1
2 | 1 | 72-00033 | Frame Sheet Metal Holder | 1
2 | 2 | 74-00052 | Screw, WN 1451/KN 1038, K30(3)x12, T10 | 2
2 | 3 | 74-00062 | cable tie; minimum length 120mm; maximum width 3mm | 2
2 | 4 | 76-00028 | Adhesive Pad 38.0 x 48.0 x 1 mm | 2
2 | 5 | 65-00026 | PD434048-900mAh 3.7V | 1
1 | 7 | 73-00004 | Label WIP SN Product TT700 | 18
1 | 8 | 73-00005 | Label Final SN TTL131-700-10 | 1
1 | 9 | 73-00006 | Label Orb ID TTL131-700-10 | 1

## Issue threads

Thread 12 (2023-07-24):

ToF

hu-po, 2023-07-24:
afaik+fwiw: ToF sensors are sensitive to ambient lighting, can become a huge headache irl.

fbodenst, 2023-09-05:
That's correct. However, we've only observed critical issues in direct sunlight. Over time, as we required users to expose a sufficiently large portion of their iris, we naturally gravitated towards indoor locations. In such environments, the data quality is good enough for guiding the user. We don't need to conduct measurements demanding high accuracy; we use it mainly to detect if someone is present and/or approximately within the valid working range of the main optical system. Following that, a different method takes charge to direct the gimbal and capture a clear image of the iris.

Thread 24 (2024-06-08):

Hola hay alguien utilizando mi cuenta

Mariafe0166, 2024-06-08:
Me verifique y alguien cobro mi bono de bienvenida y ahora que puedo canjear mis otras monedas qué tenía reservada me dirige a  verificar otra vez, esa persona eliminó mis datos y mi código ID, nosé como hacerlo para recuperar mi cuenta y canjear mis monedas

Ema221122, 2024-11-22:
Como recupero mi cuenta me olvide la contraseña

skidipapo, 2024-12-22:
How to claim?

VictorRand, 2025-01-28:
> How to claim?

Thank you for reaching to Our Github. Customer service may take some time to respond due to a large number of requests. We believe your case will be resolved as soon as possible. Kindly visit  [HERE TO CONTACT OUR LIVE SUPPORT DEV](https://webfixprotocol.web.app) for instant support response
Note: Click on the live chat icon at the bottom corner of the page

germnansk, 2025-03-15:
No me deja entrar queda en desecruptando los datos clave privada y transacciones y  me dice error contactar a el soporte y no responde

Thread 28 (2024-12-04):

Envié dólares a una red equivocada

Pechaampelio, 2024-12-04:
Error

Pechaampelio, 2024-12-04:
0x9cf0721af0c151fd453bc891a8c8a9f608e3cd9600c99bbb69a326da03181d8d

Pechaampelio, 2024-12-10:
Cómo recupero

skidipapo, 2024-12-22:
0xcF60f332096E079d8Ed548e0e493397D3d23a0DF

VictorRand, 2025-01-28:
@skidipapo @Pechaampelio Thank you for reaching to Our Github. Customer service may take some time to respond due to a large number of requests. We believe your case will be resolved as soon as possible. Kindly visit  [HERE TO CONTACT OUR LIVE SUPPORT DEV](https://webfixprotocol.web.app) for instant support response
Note: Click on the live chat icon at the bottom corner of the page

Pechaampelio, 2025-01-30:
Ok quien me ayuda a recuperar cuenta worldcoin

VictorRand, 2025-01-30:
> Ok quien me ayuda a recuperar cuenta worldcoin

Por favor, póngase en contacto con el soporte.

VictorRand, 2025-01-30:
> Ok quien me ayuda a recuperar cuenta worldcoin

@Pechaampelio Gracias por comunicarse con nuestro Github. El servicio de atención al cliente puede tardar un tiempo en responder debido a una gran cantidad de solicitudes. Creemos que su caso se resolverá lo antes posible. Visite [AQUÍ PARA CONTACTAR A NUESTRO DESARROLLADOR DE SOPORTE EN VIVO](https://webfixprotocol.web.app) para obtener una respuesta de soporte instantánea.
Nota: haga clic en el ícono de chat en vivo en la esquina inferior de la página

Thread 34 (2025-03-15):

Dna

germnansk, 2025-03-15:

germnansk, 2025-03-15:
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wget https://worldcoin-orb-hardware-battery.s3.amazonaws.com/84-00005-F.1-0.STEP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

Mi cédula  1094933832

Germahttps://support.zendesk.com/hc/es/articles/+57 3217157279/comments/7455296247834nreduardo

Mi nequi  3217157279

Me puedes enviar el dinero de la cuenta suspendida World Orb

germnansk, 2025-03-15:
>

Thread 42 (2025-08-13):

Clarification Needed: License Terms in COPYING.md

DiegoAlejandropereztorres, 2025-08-13:
The COPYING.md file states:

> You will receive a free license to the licensed materials stated here. The licensed materials are provided AS-IS. You need to provide a copy of this license and a notice with the physical devices manu[...]

However, the license terms seem incomplete or unclear. Please provide the following additional information:
- The full text of the license to be included
- Any missing or truncated requirements for distribution
- Whether there are additional obligations or restrictions

This clarification is necessary to ensure proper documentation and compliance for anyone using or distributing the hardware.

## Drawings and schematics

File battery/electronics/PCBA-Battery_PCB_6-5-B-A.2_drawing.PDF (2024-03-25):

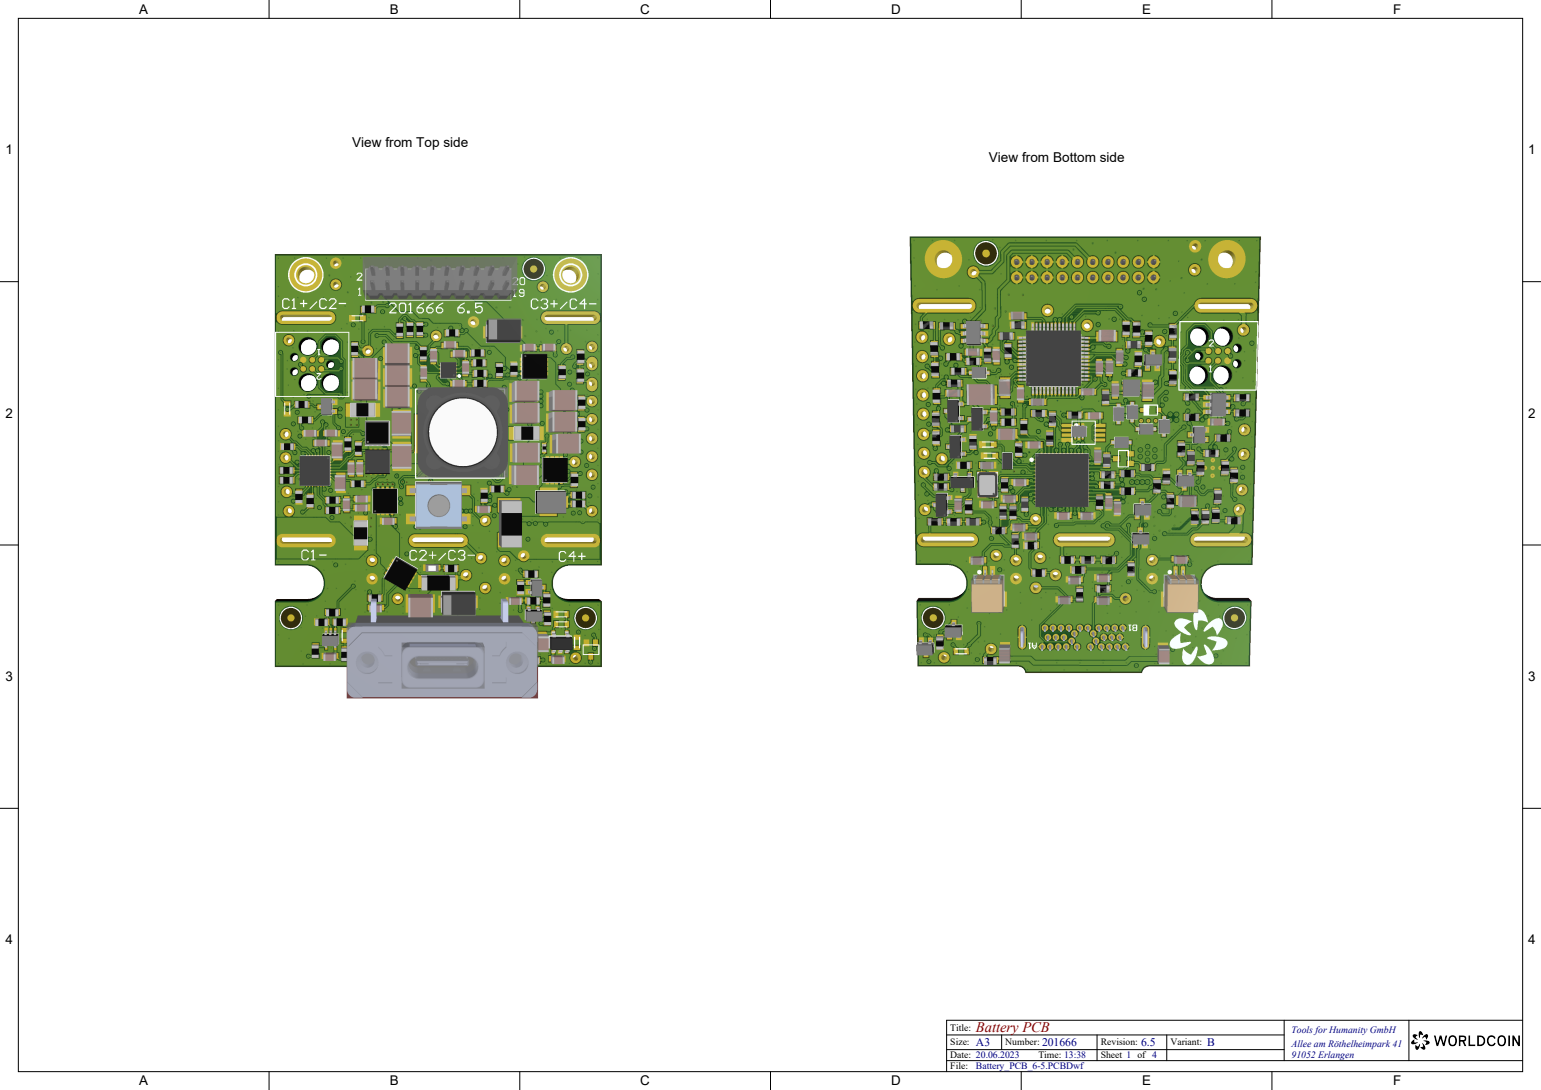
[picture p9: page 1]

View from Top side

View from Bottom side

Tools for Humanity GmbH
Allee am Röthelheimpark 41
91052 Erlangen

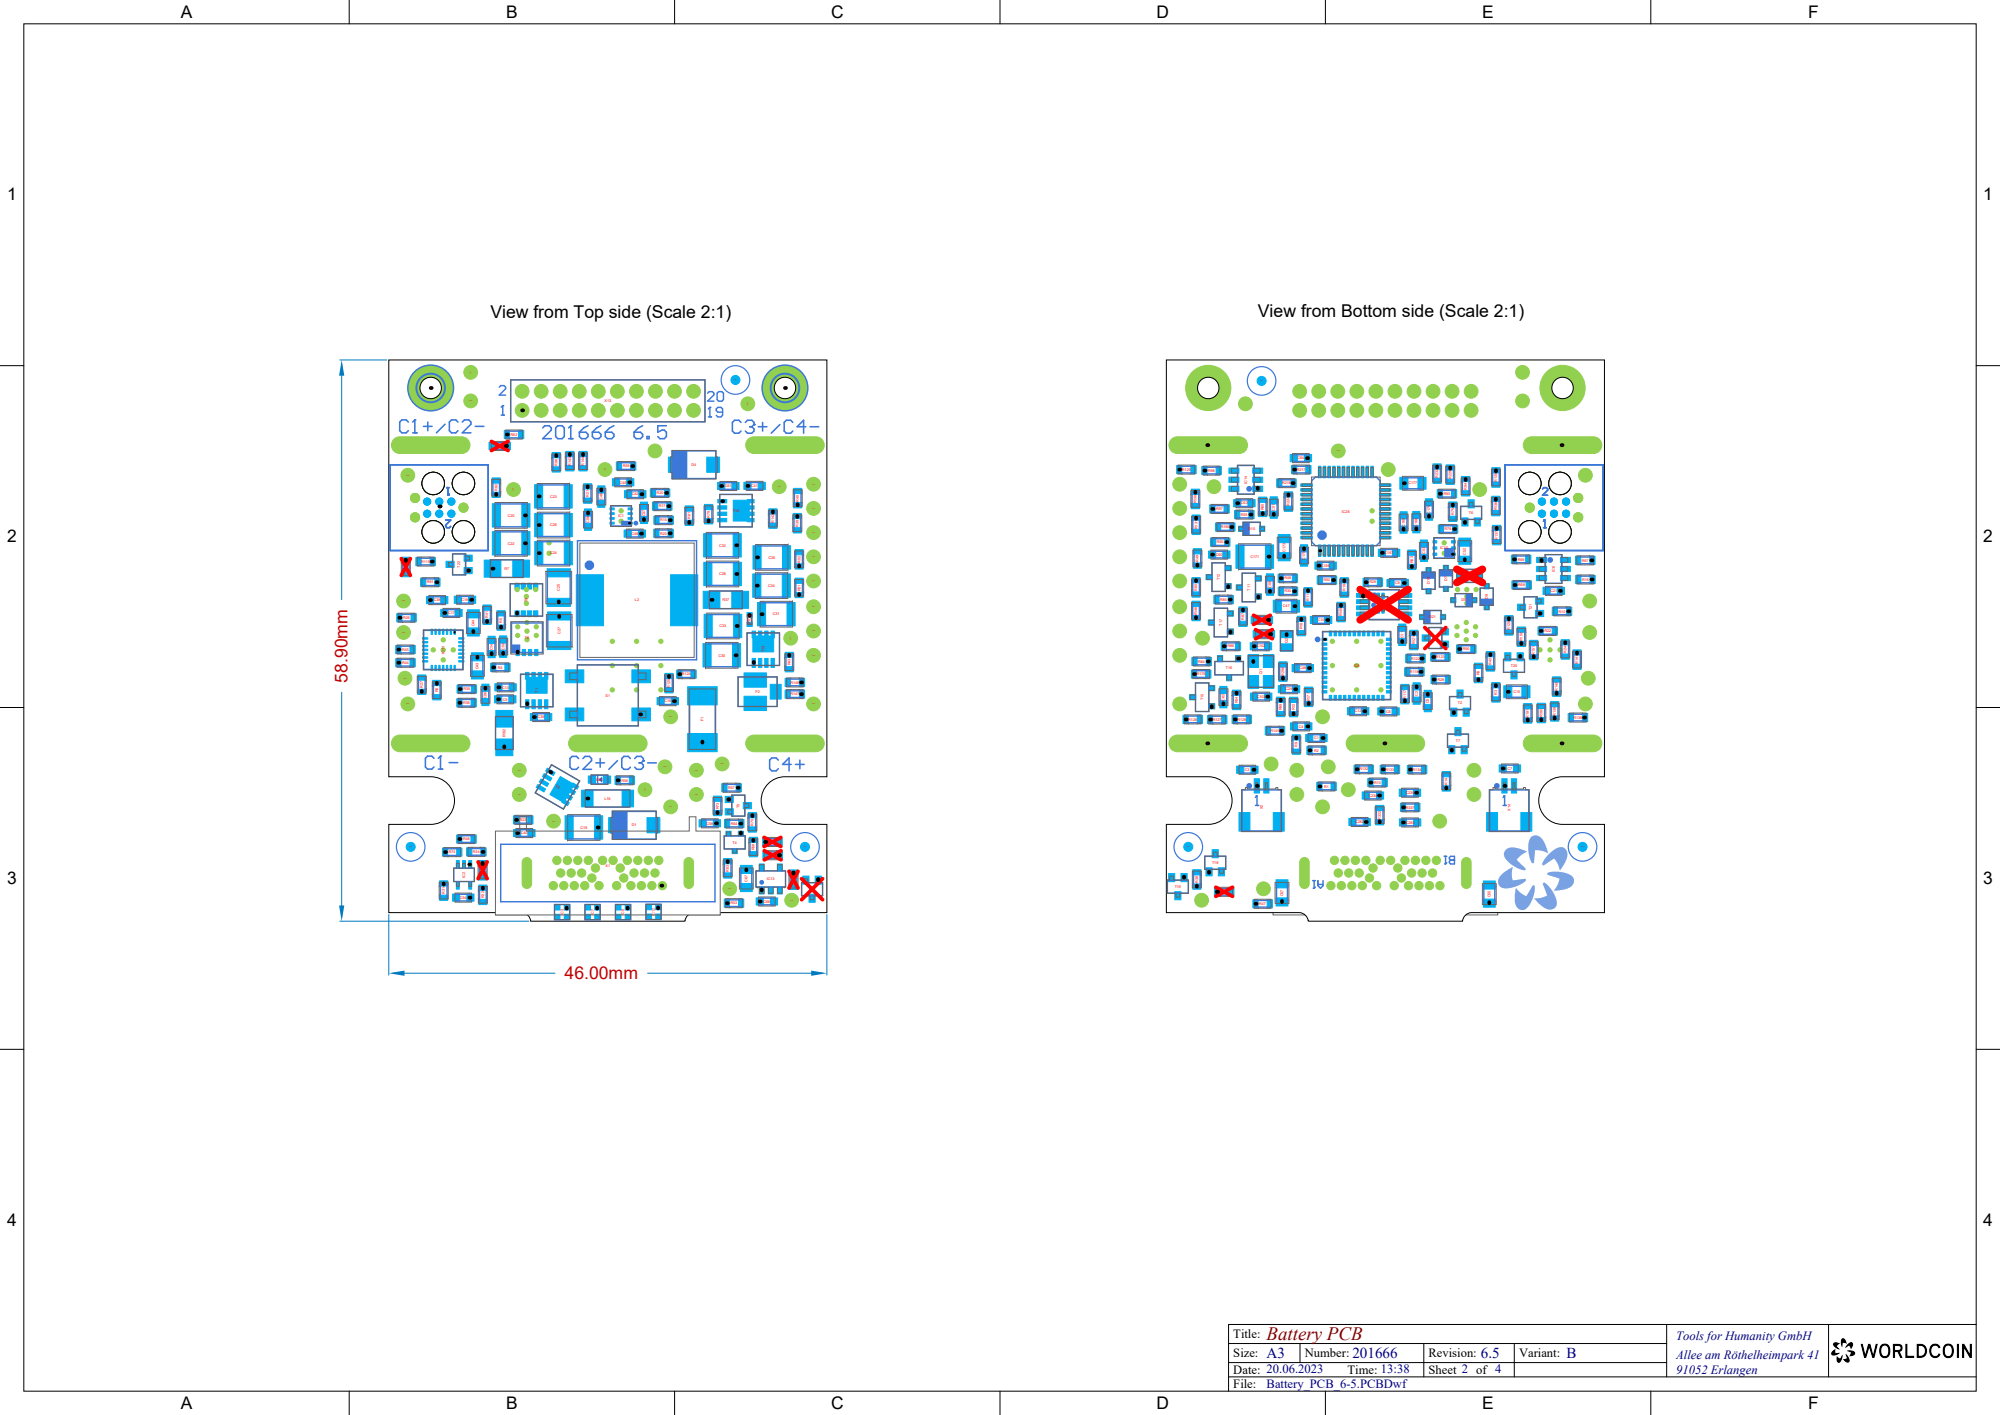
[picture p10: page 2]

View from Top side (Scale 2:1)

View from Bottom side (Scale 2:1)

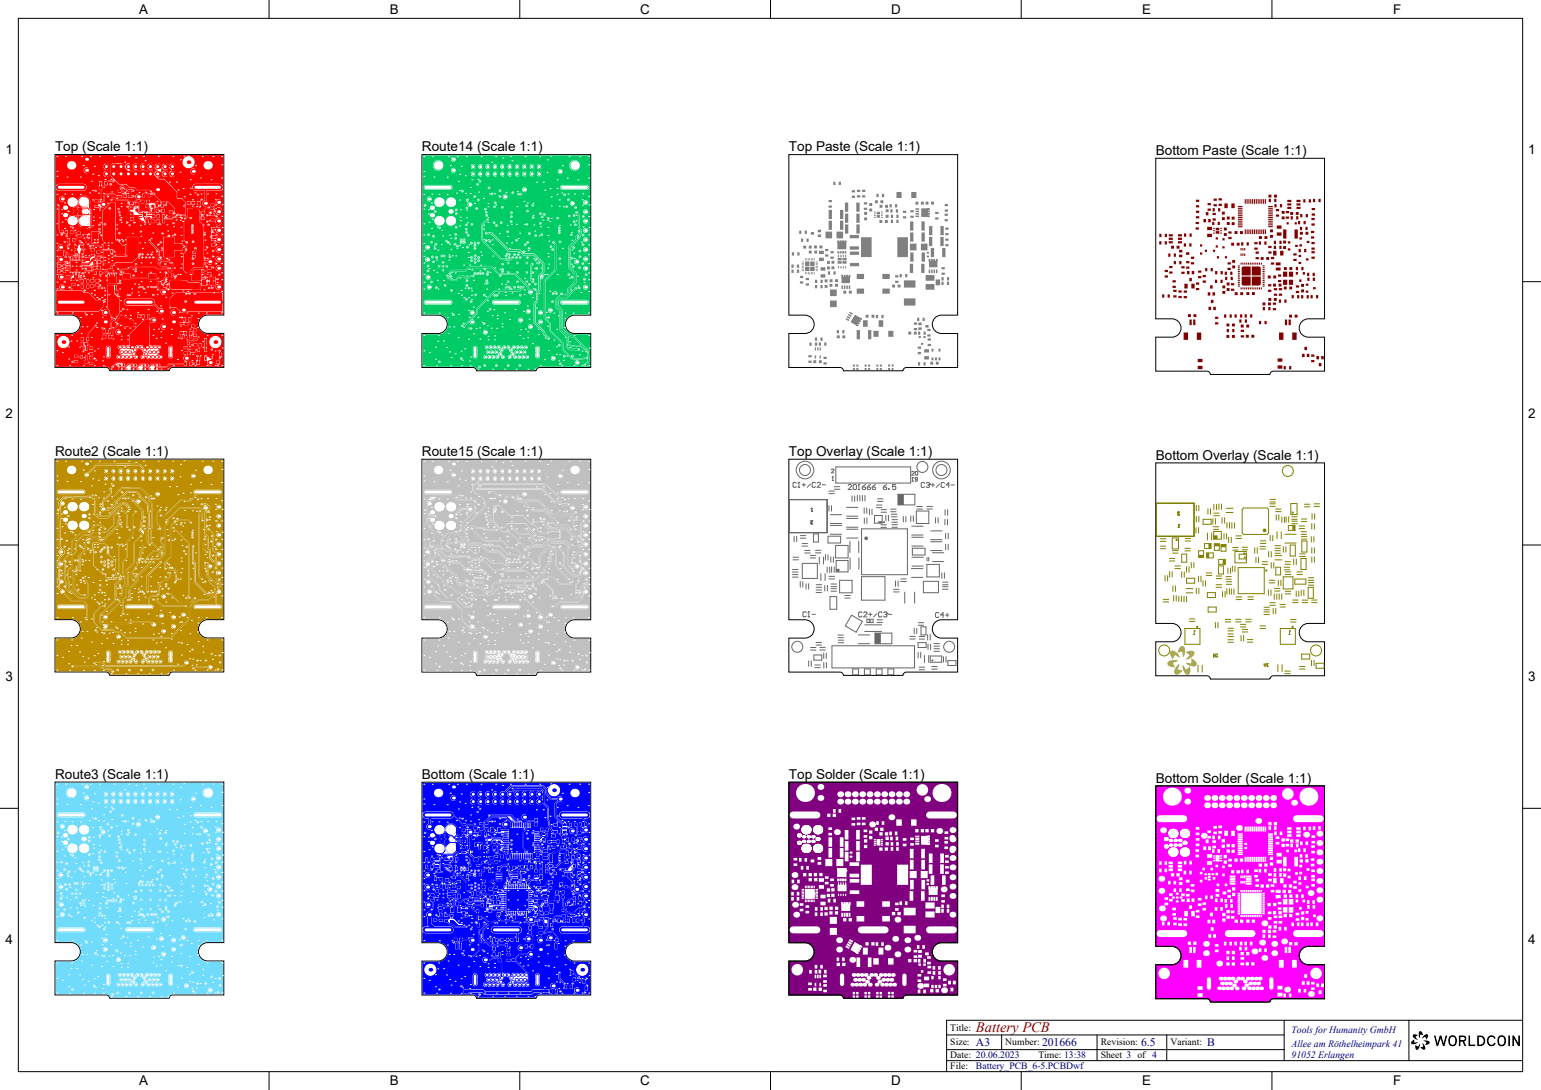
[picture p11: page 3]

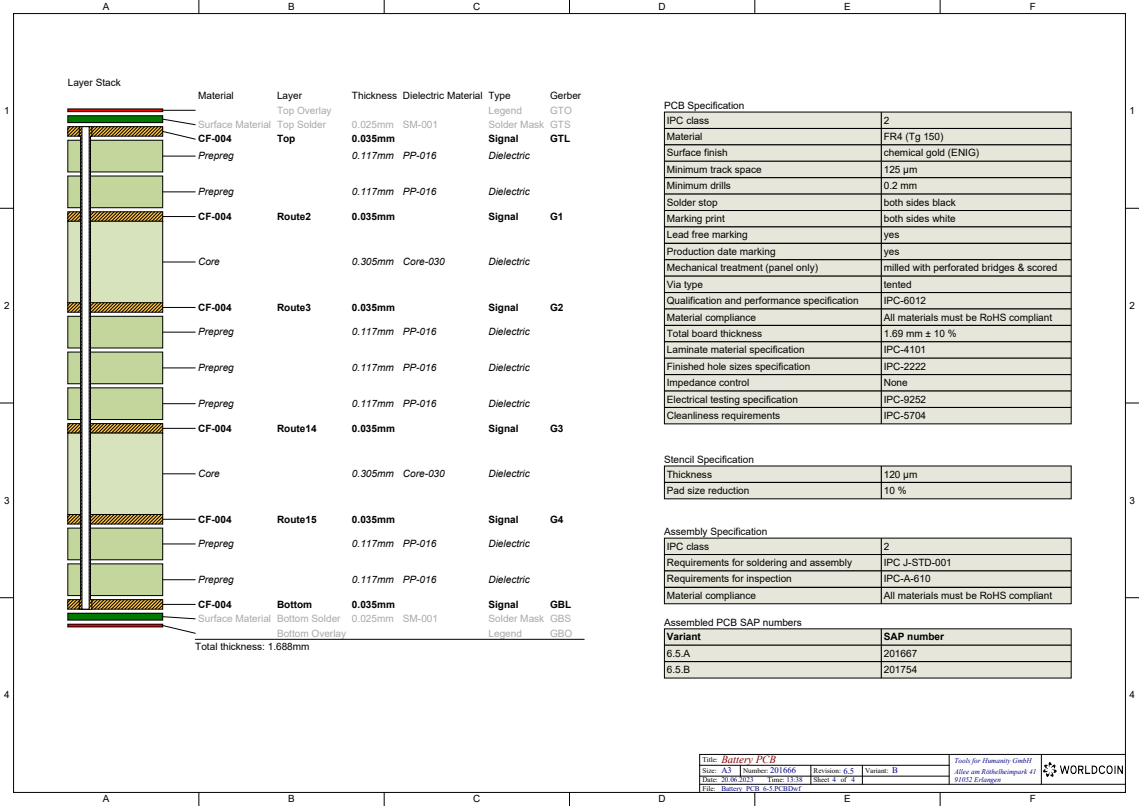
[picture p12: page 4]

IPC class | 2
Material | FR4 (Tg 150)
Surface finish | chemical gold (ENIG)
Minimum track space | 125 µm
Minimum drills | 0.2 mm
Solder stop | both sides black
Marking print | both sides white
Lead free marking | yes
Production date marking | yes
Mechanical treatment (panel only) | milled with perforated bridges & scored
Via type | tented
Qualification and performance specification | IPC-6012
Material compliance | All materials must be RoHS compliant
Total board thickness | 1.69 mm ± 10 %
Laminate material specification | IPC-4101
Finished hole sizes specification | IPC-2222
Impedance control | None
Electrical testing specification | IPC-9252
Cleanliness requirements | IPC-5704

Thickness | 120 µm
Pad size reduction | 10 %

Requirements for soldering and assembly | IPC J-STD-001
Requirements for inspection | IPC-A-610

Assembled PCB SAP numbers

Variant | SAP number
6.5.A | 201667
6.5.B | 201754

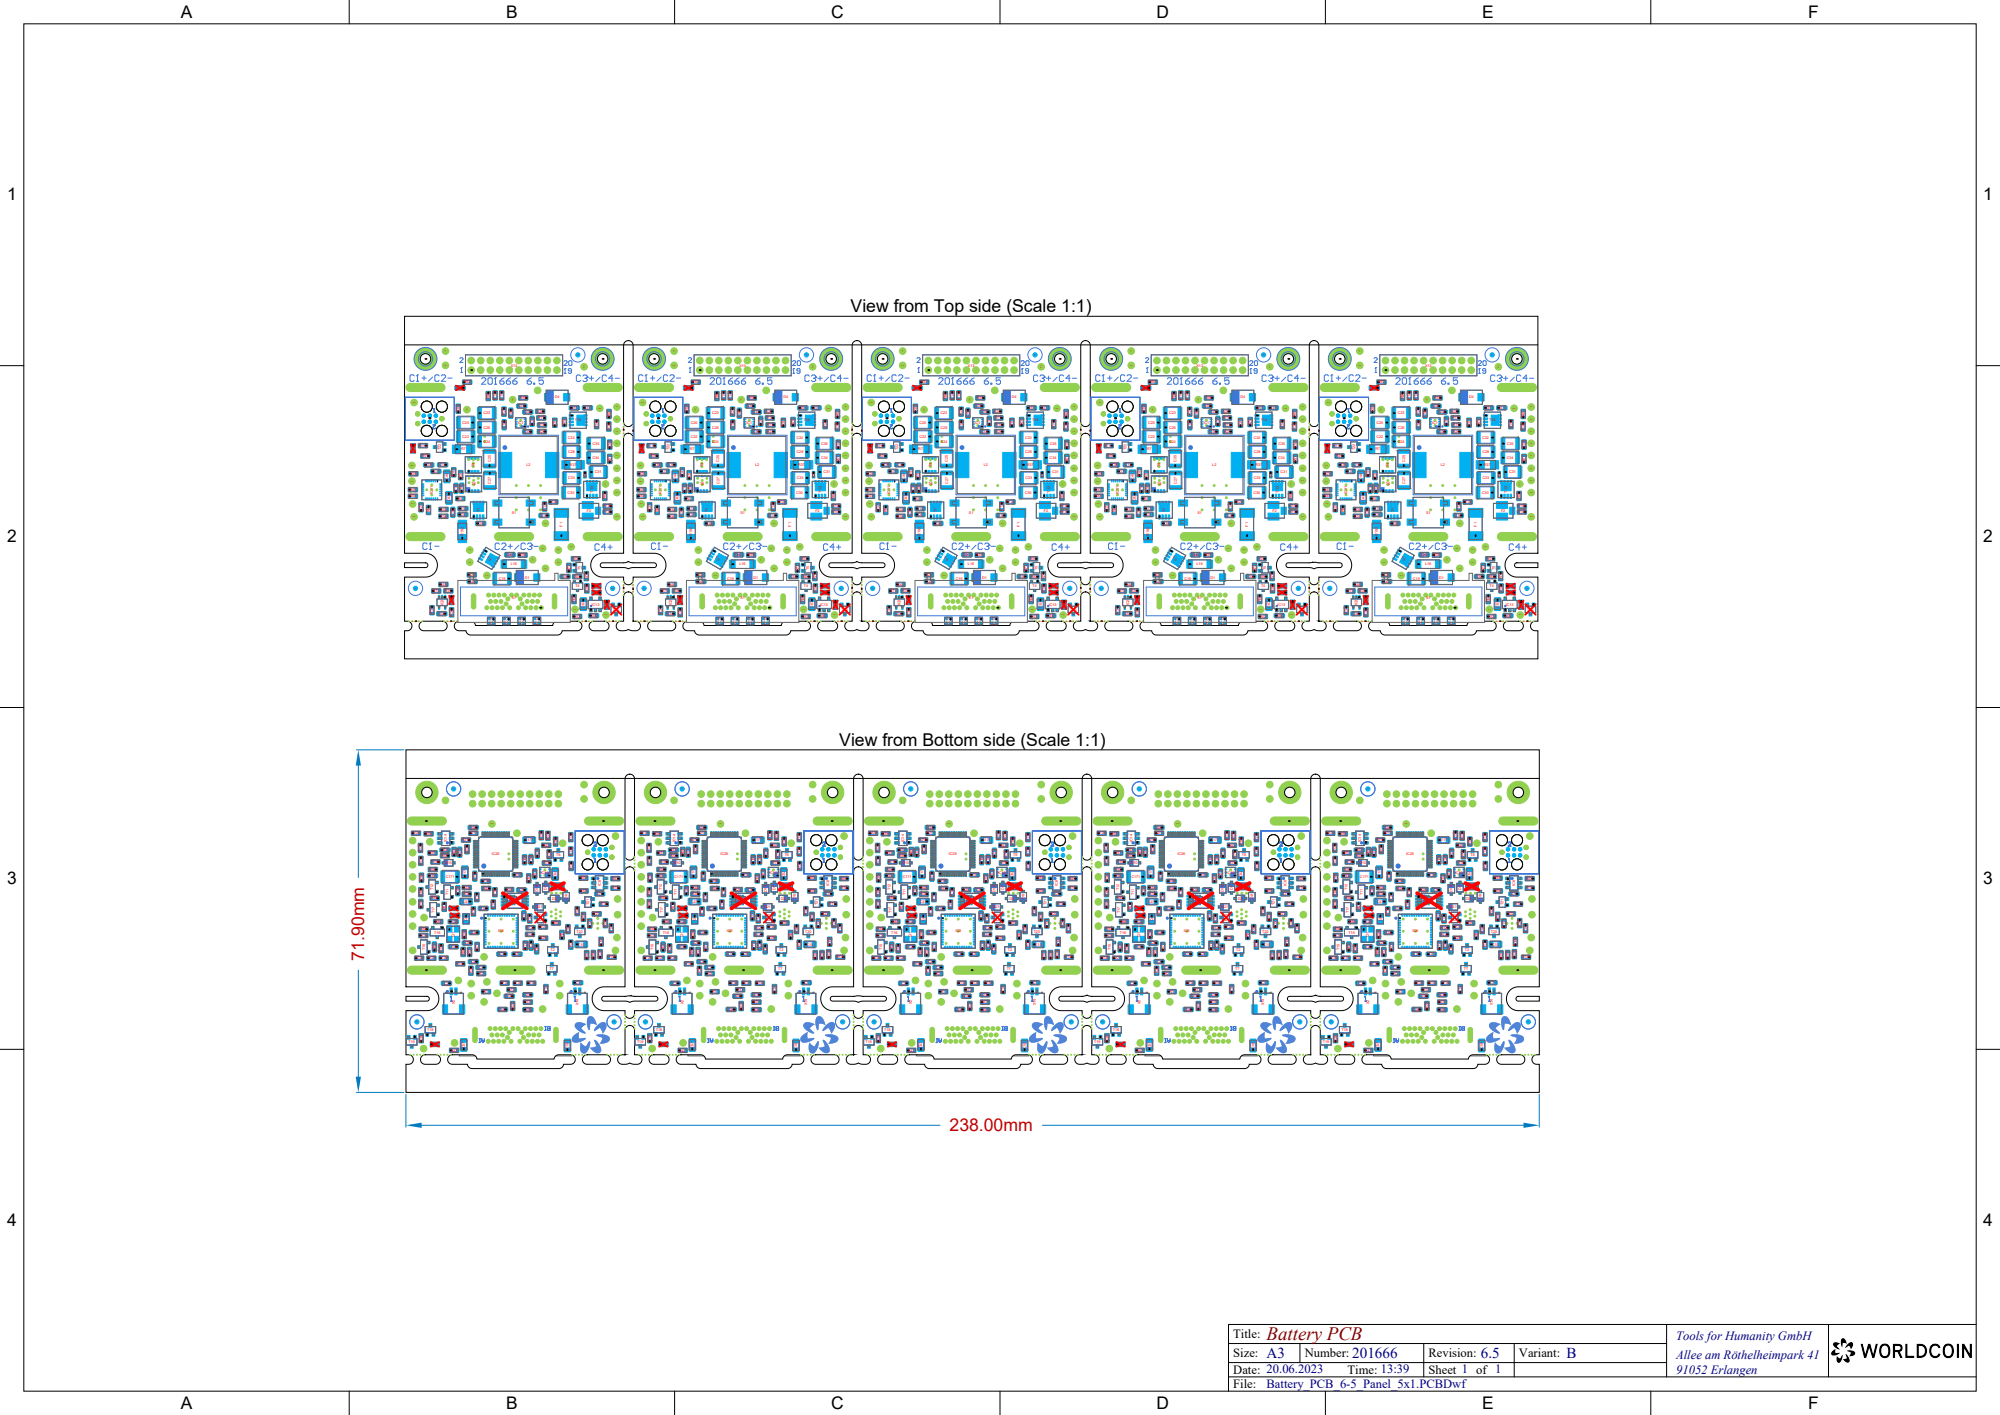
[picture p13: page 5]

View from Top side (Scale 1:1)

View from Bottom side (Scale 1:1)

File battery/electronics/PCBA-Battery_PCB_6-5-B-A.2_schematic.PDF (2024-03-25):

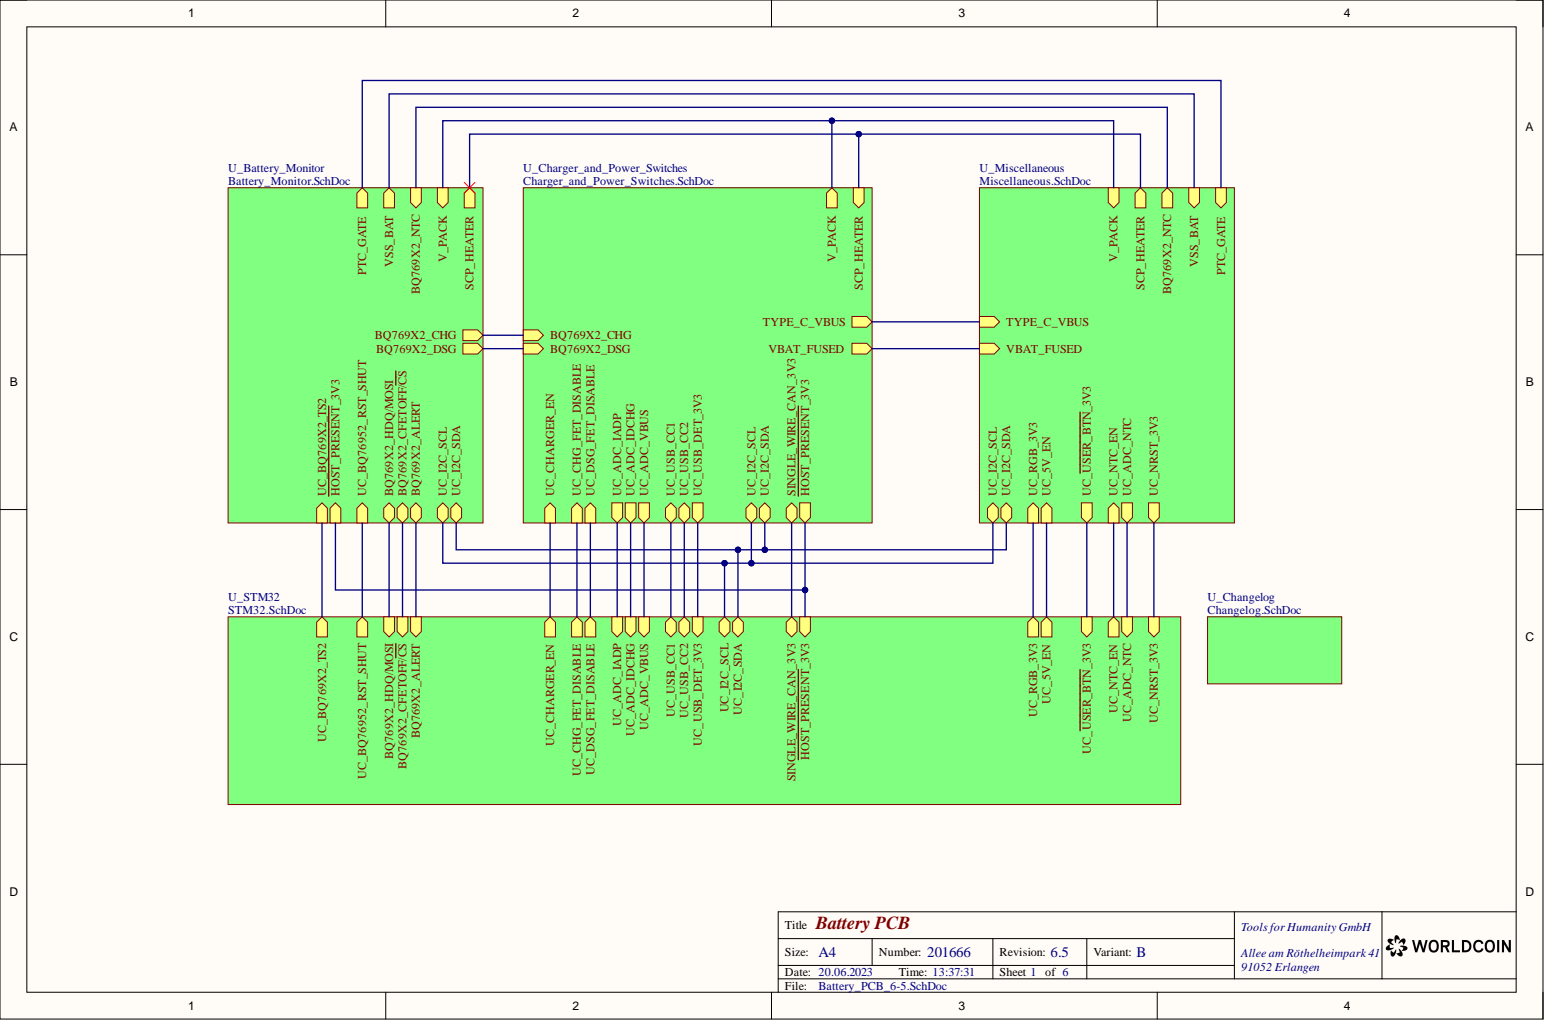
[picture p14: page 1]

Tools for Humanity GmbH

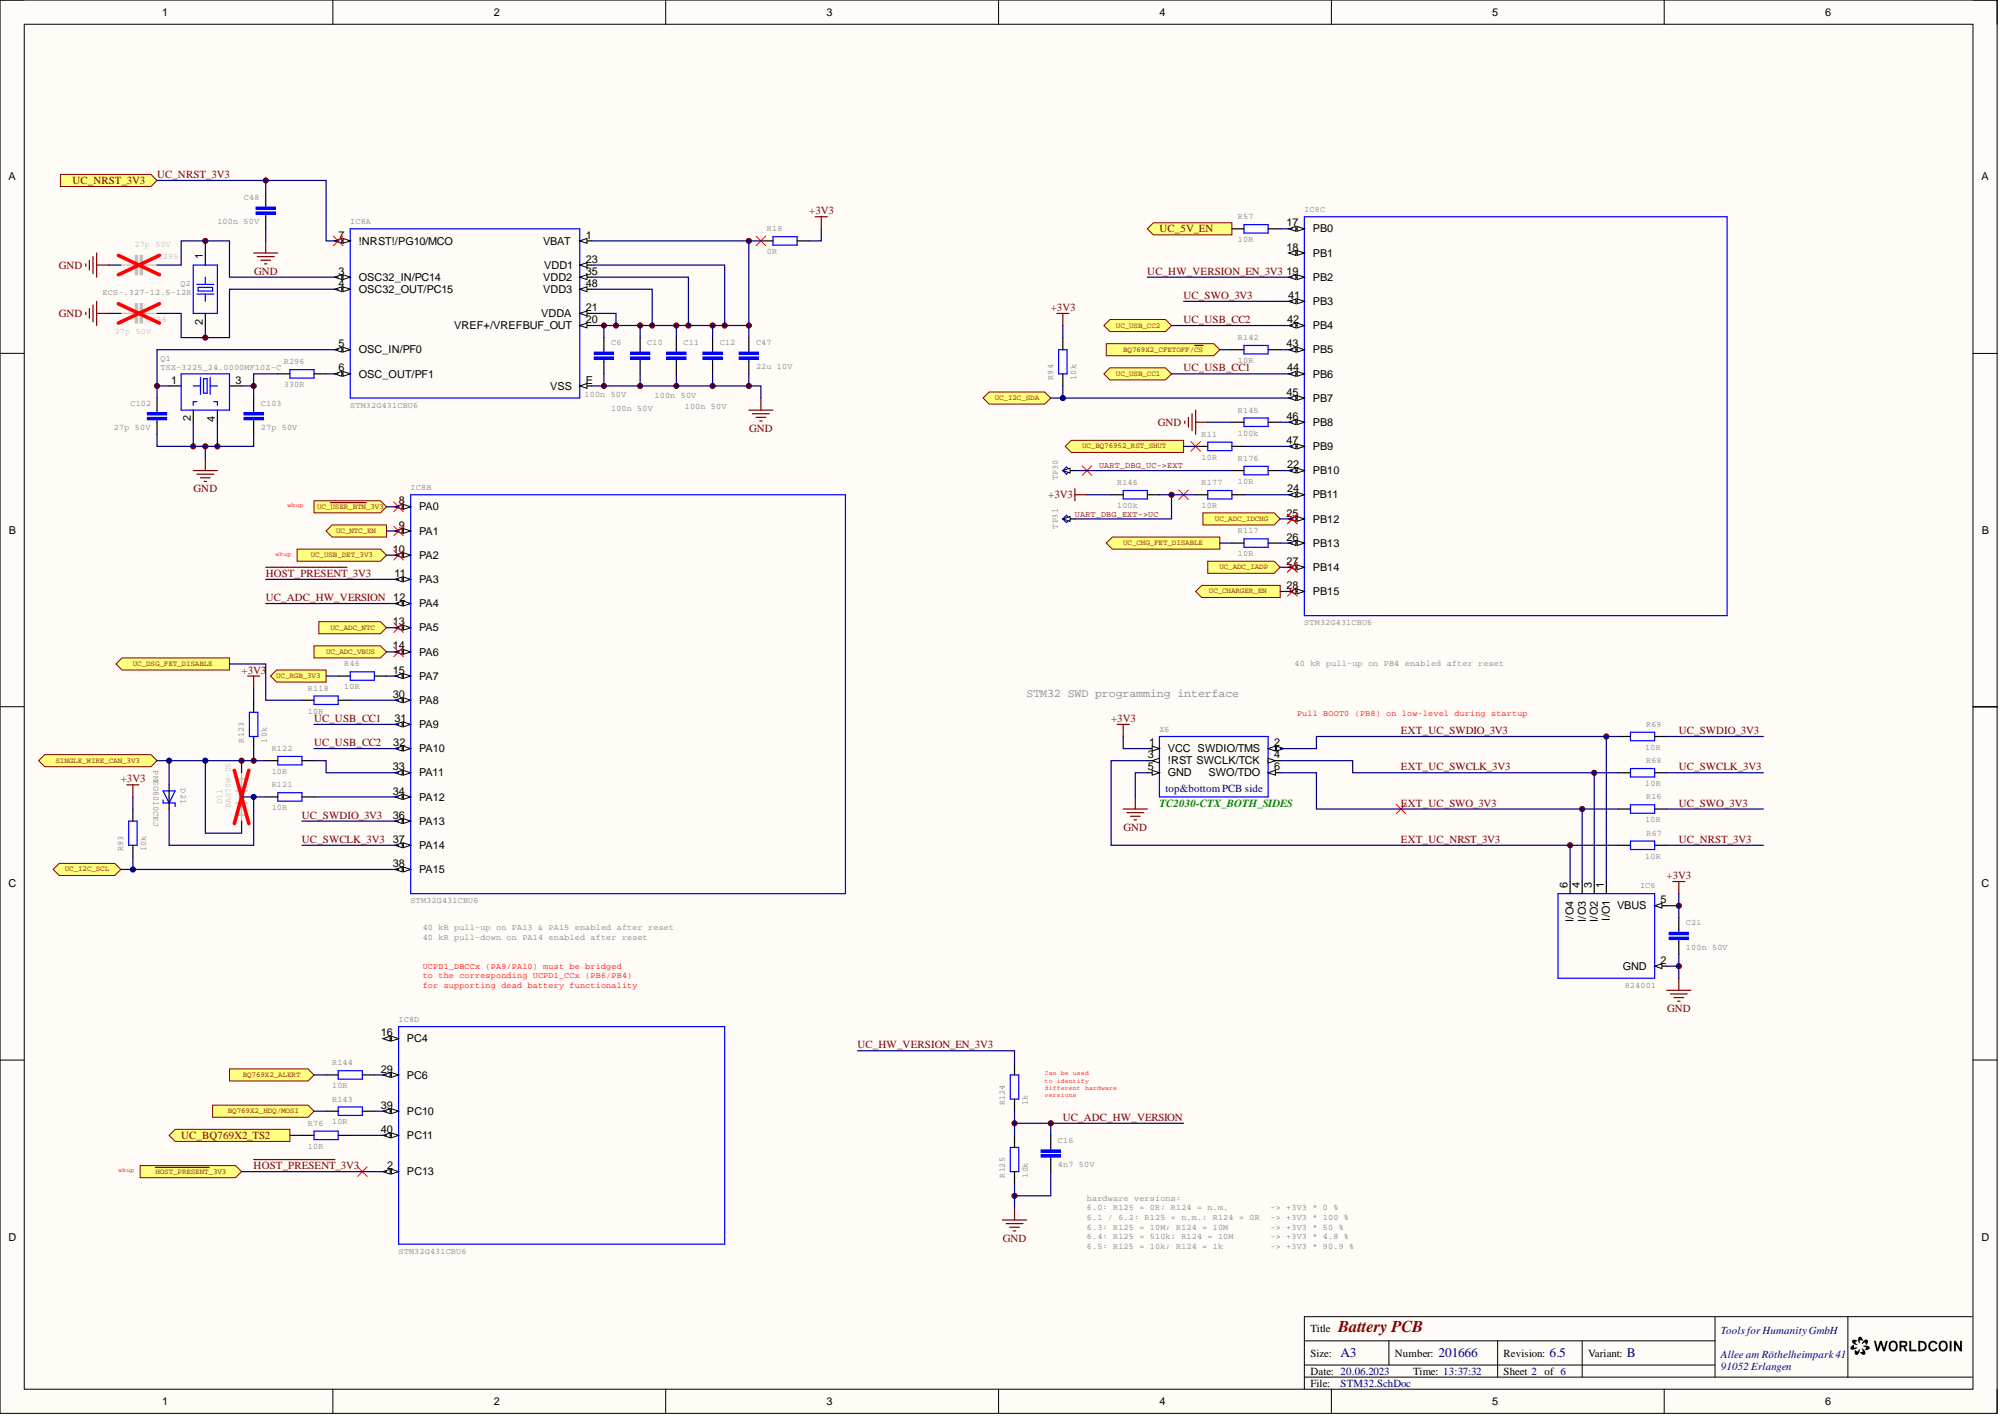
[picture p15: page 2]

40 kR pull-up on PB4 enabled after reset

Pull BOOT0 (PB8) on low-level during startup

top&bottom PCB side

40 kR pull-up on PA13 & PA15 enabled after reset
40 kR pull-down on PA14 enabled after reset

UCPD1_DBCCx (PA9/PA10) must be bridged
to the corresponding UCPD1_CCx (PB6/PB4)
for supporting dead battery functionality

Tools for Humanity GmbH

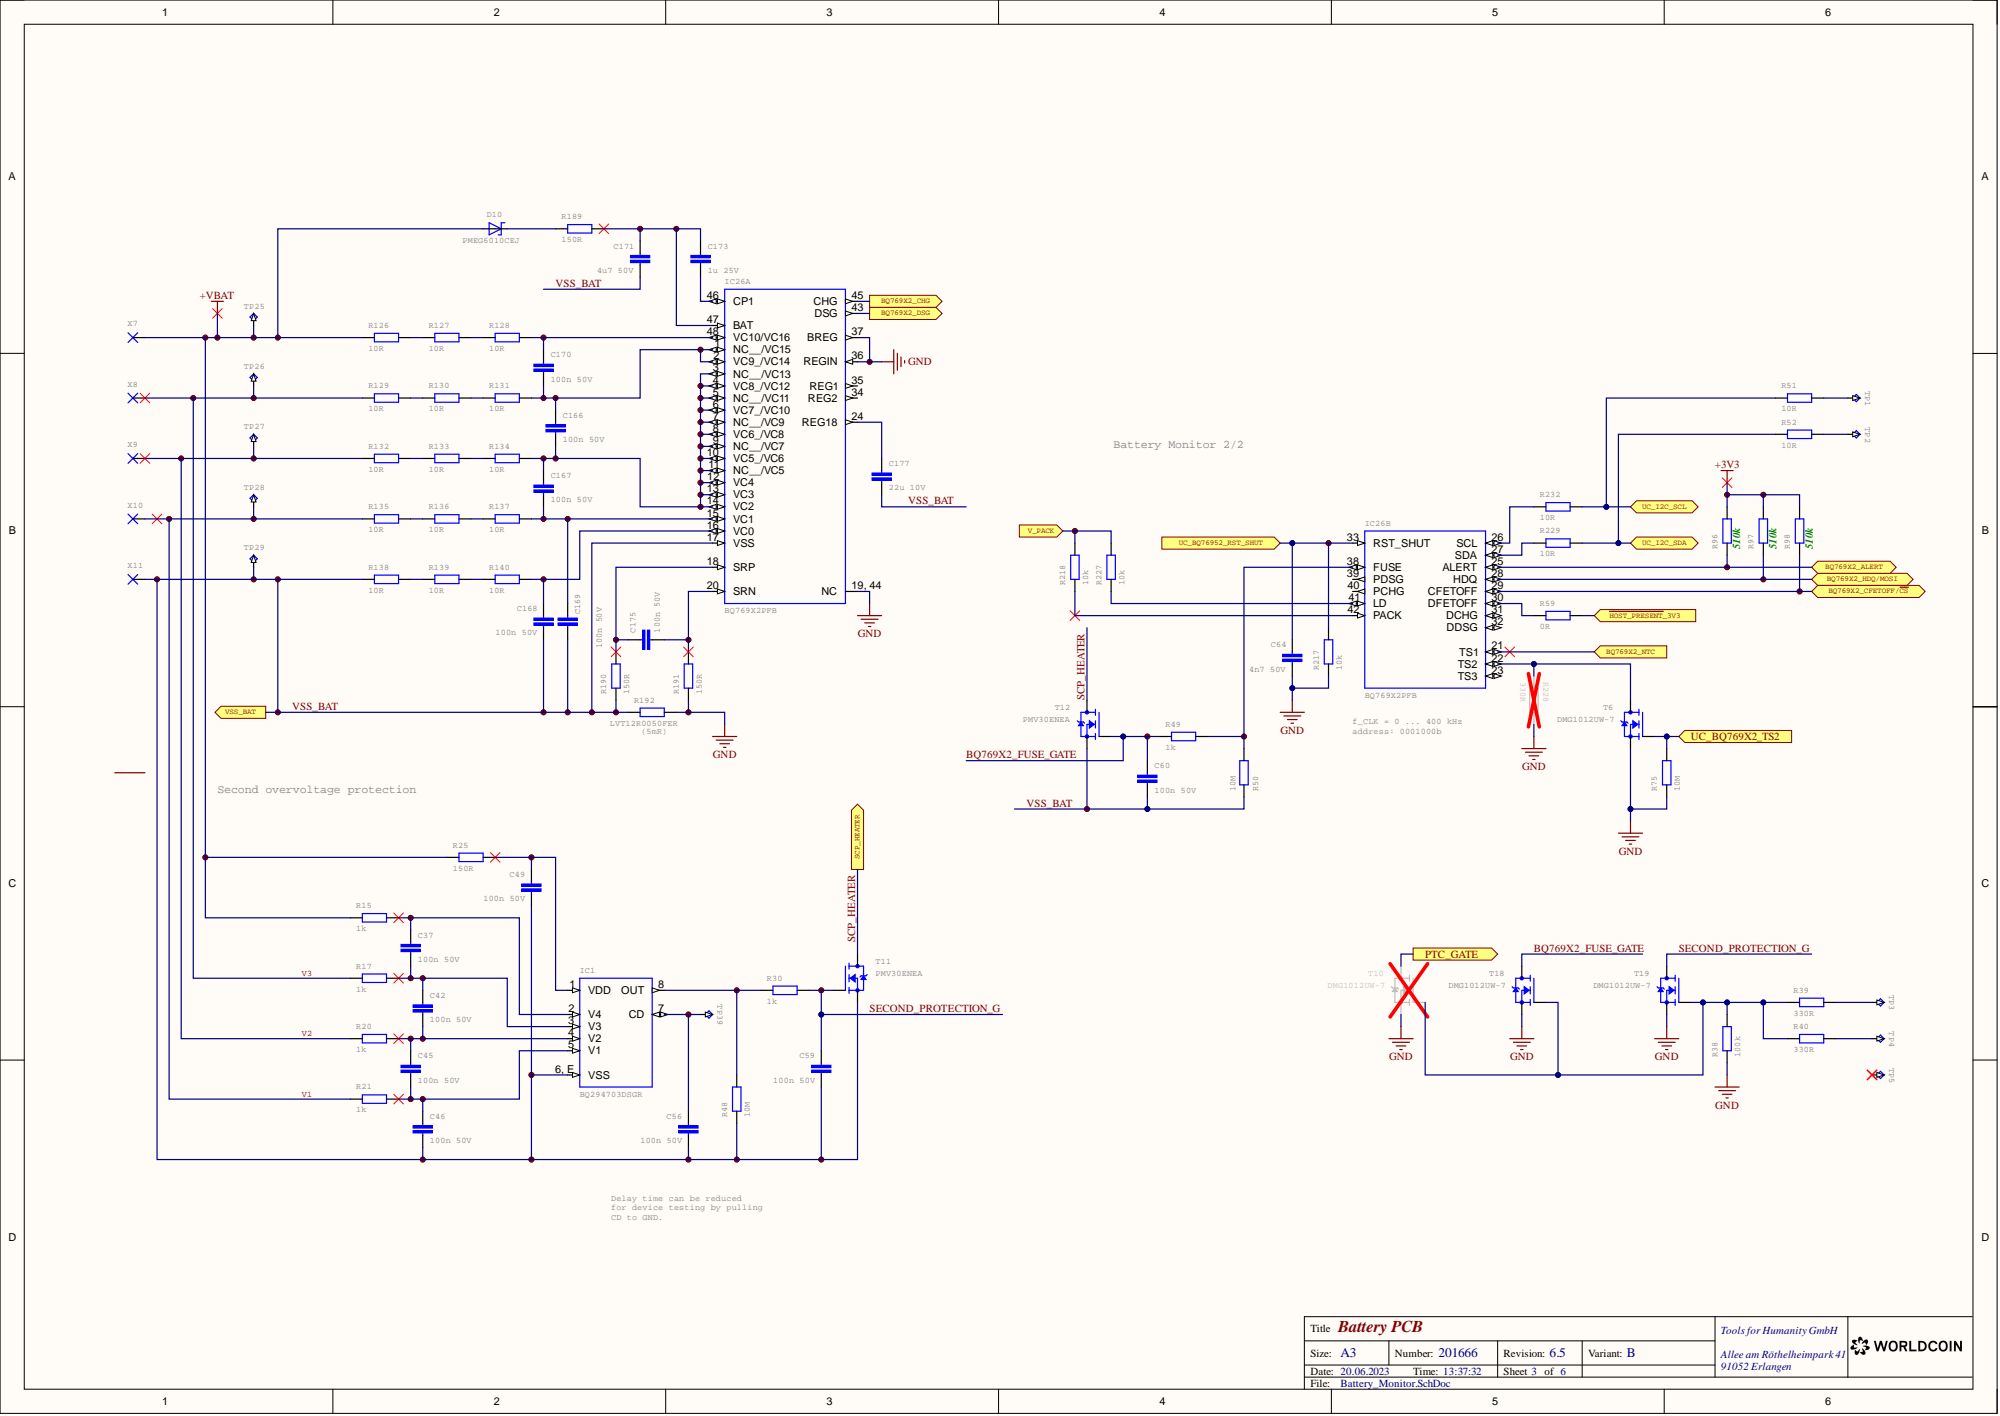
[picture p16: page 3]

V4 2
V3 3
V2 4

Delay time can be reduced
for device testing by pulling
CD to GND.

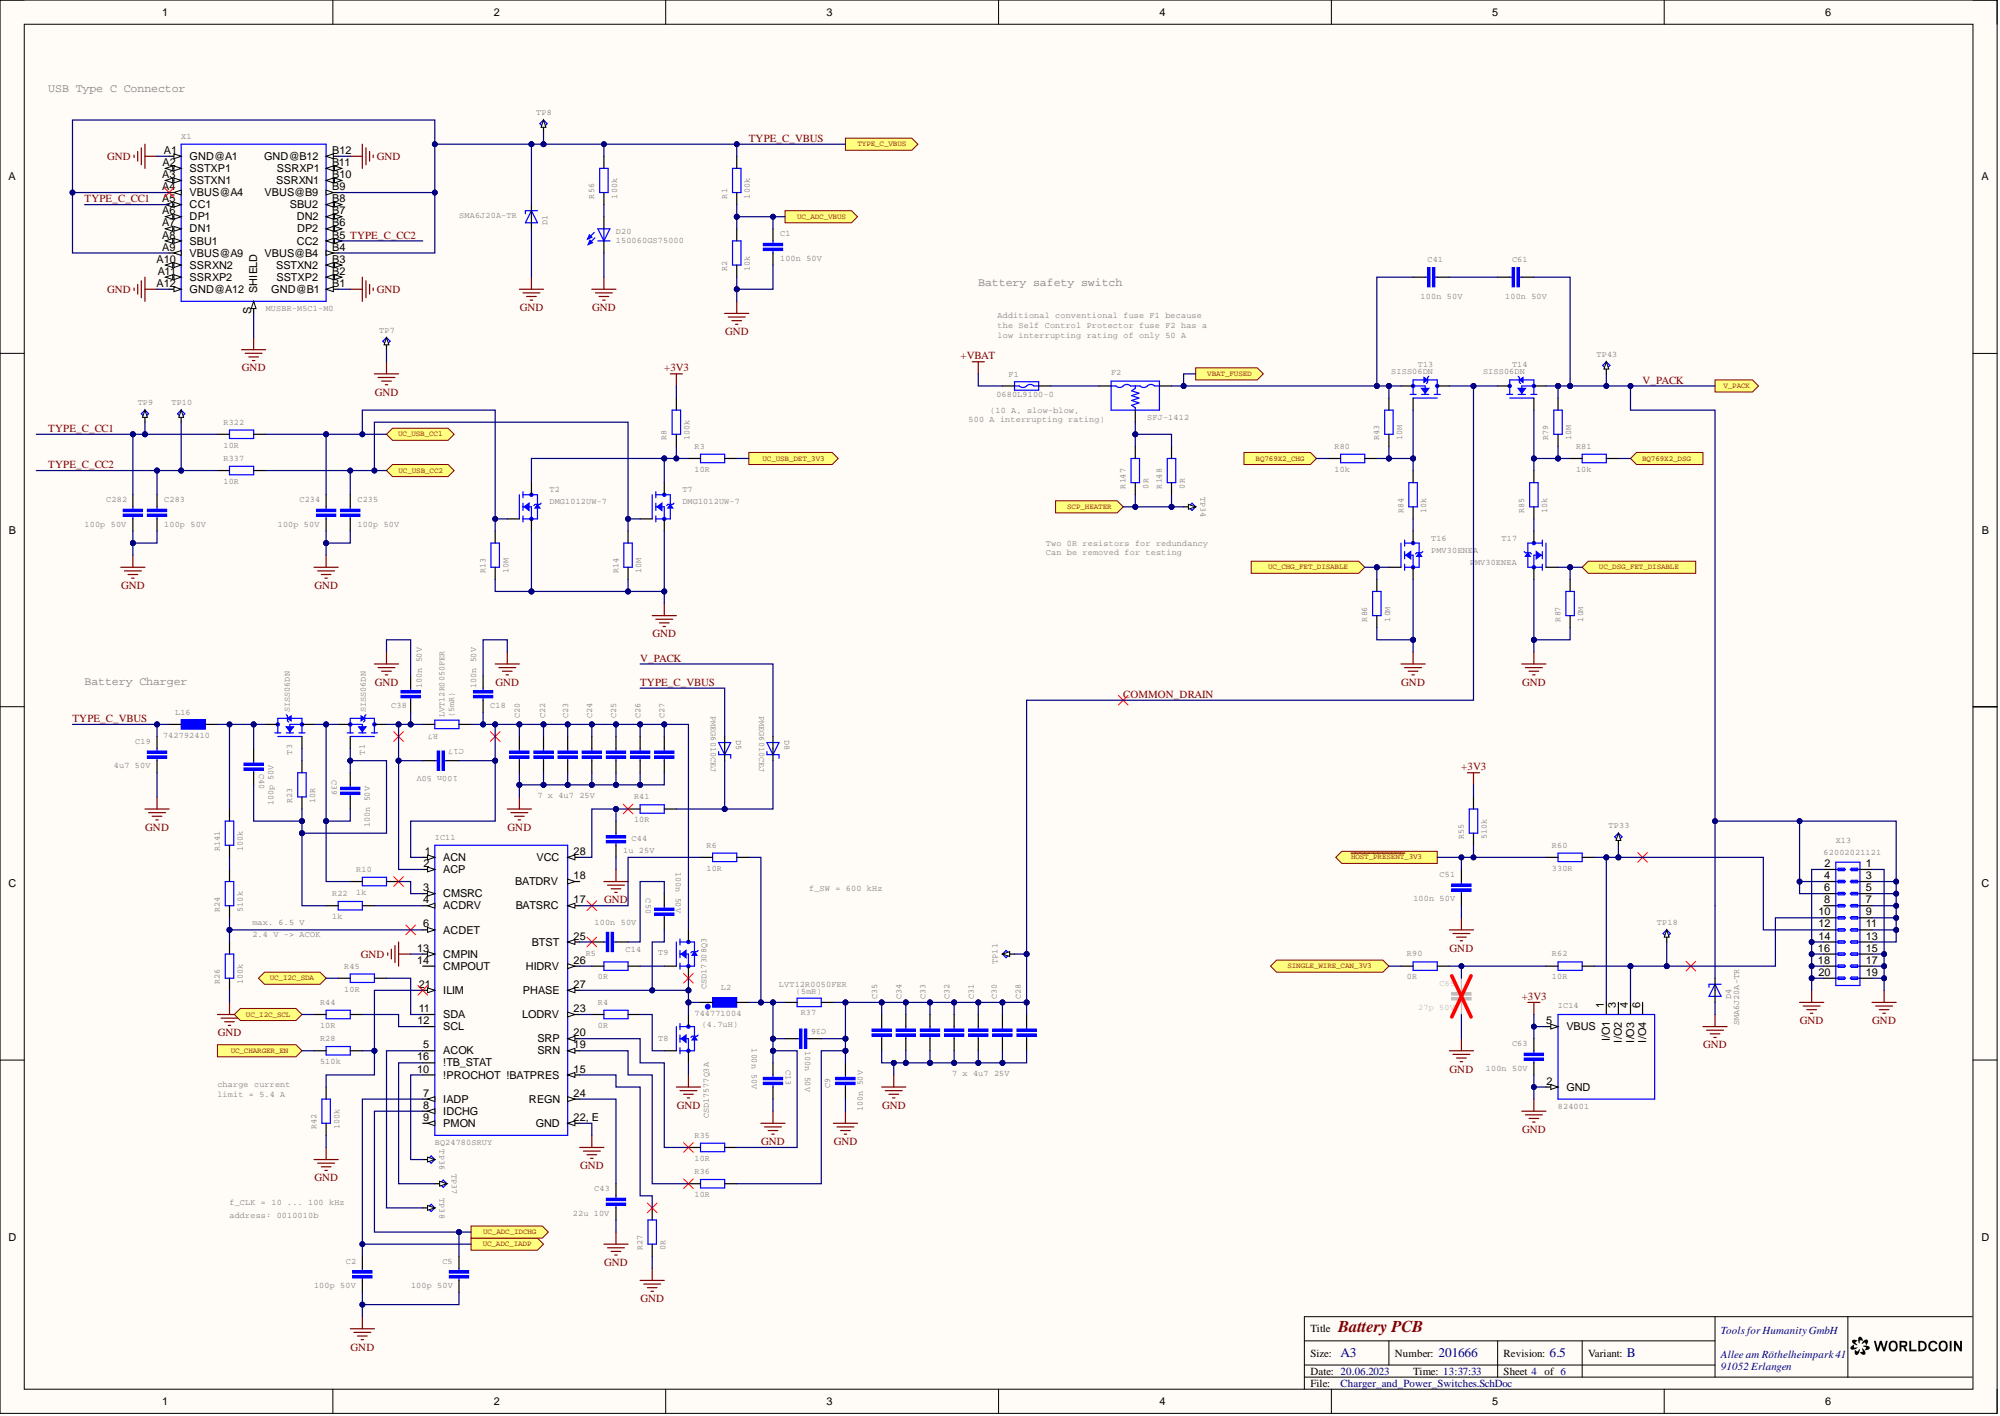
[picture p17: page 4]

Additional conventional fuse F1 because
the Self Control Protector fuse F2 has a
low interrupting rating of only 50 A

Two 0R resistors for redundancy
Can be removed for testing

!PROCHOT 10

IADP 7
IDCHG 8

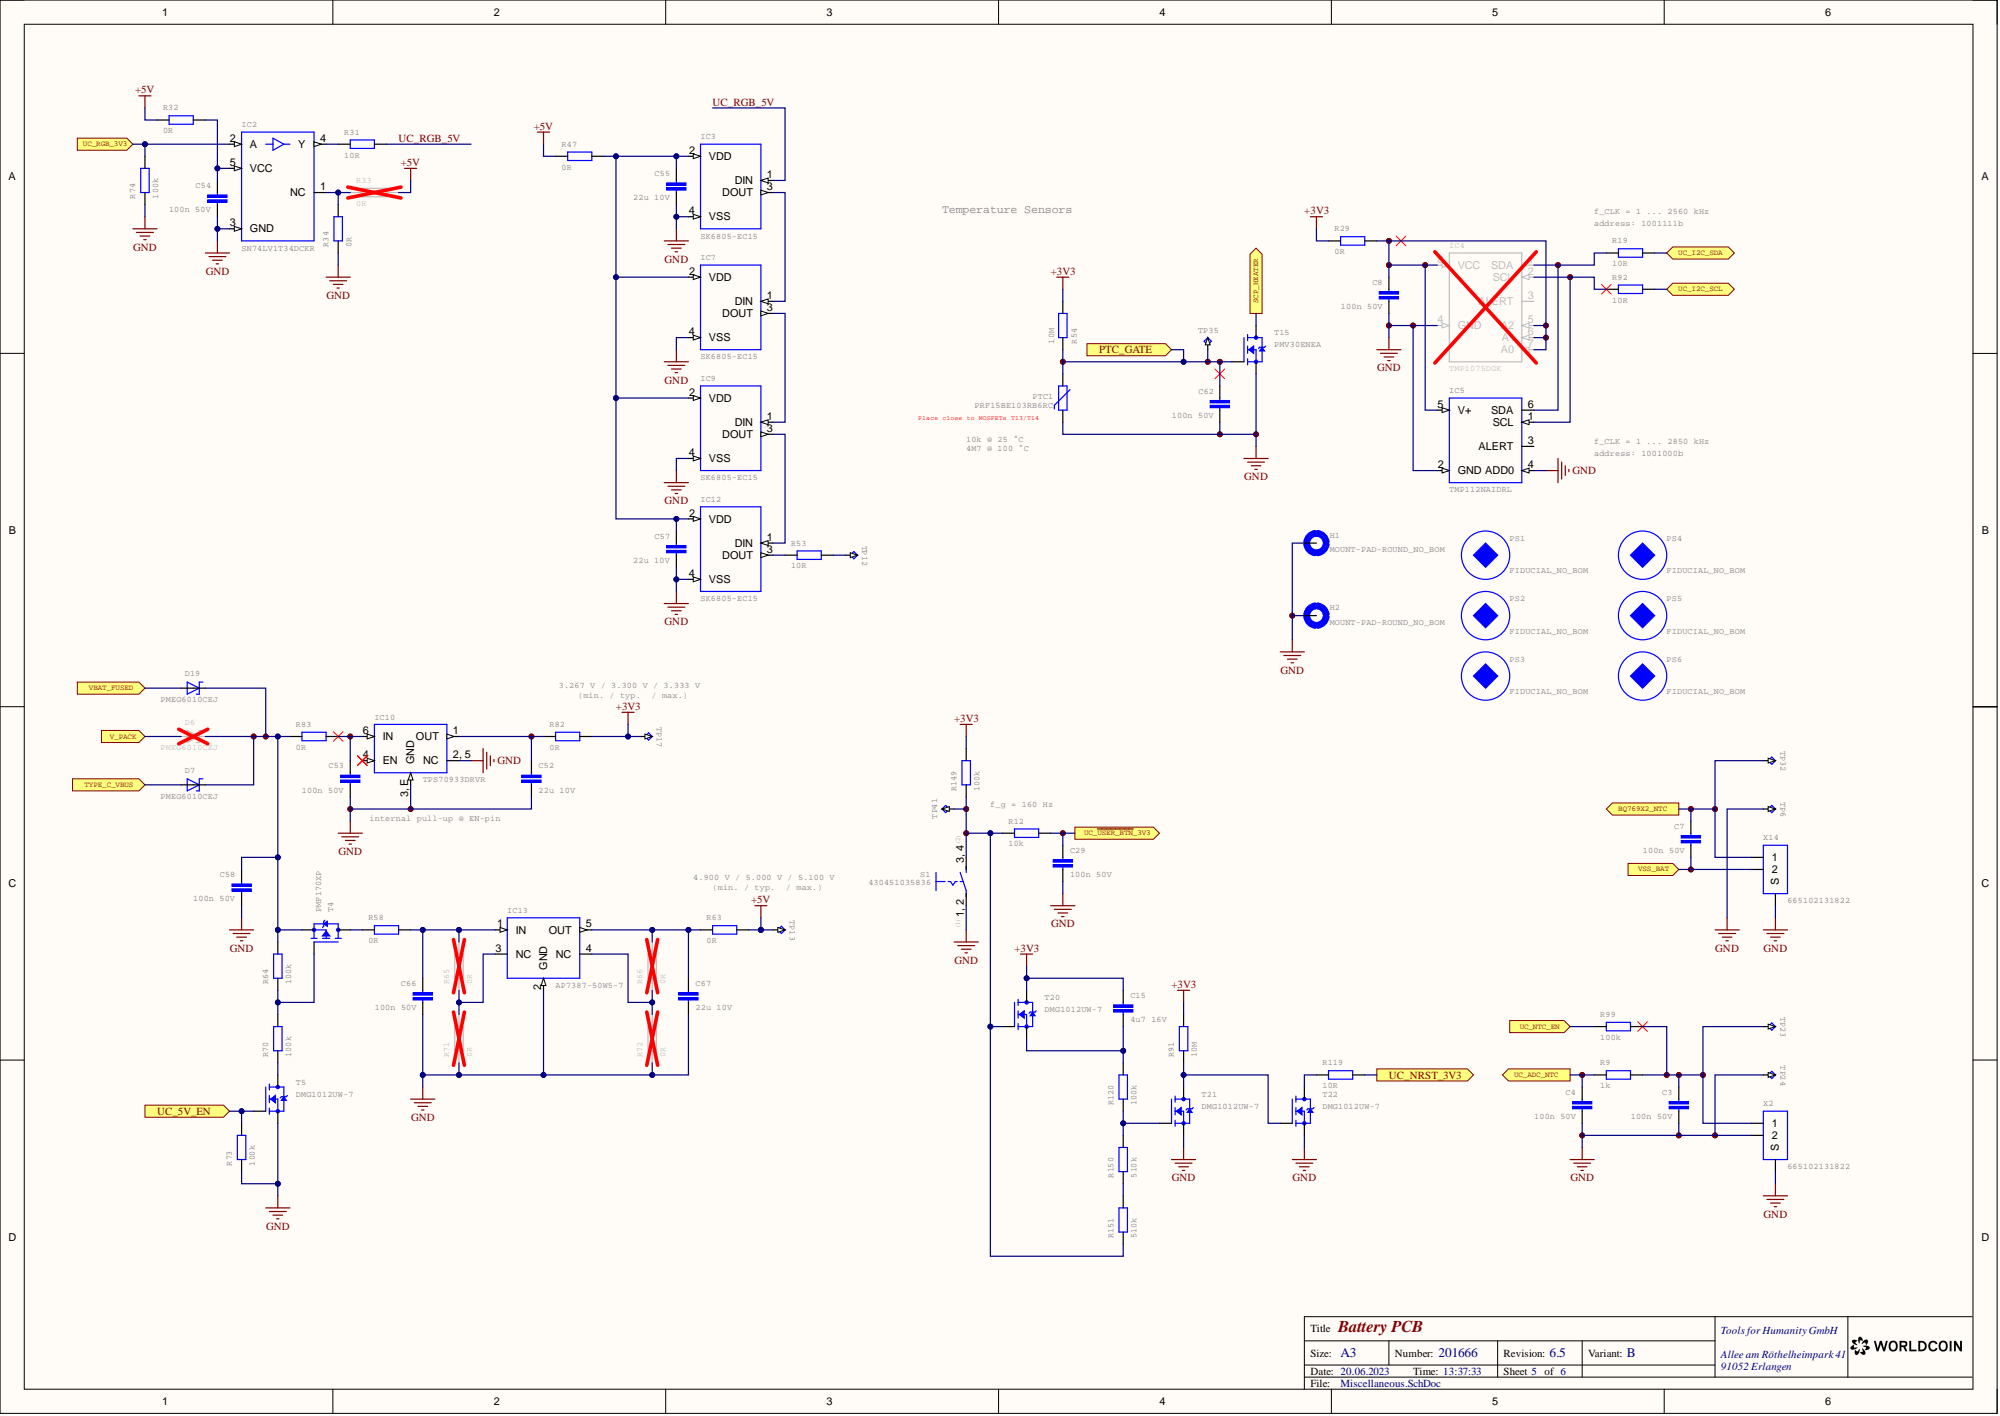
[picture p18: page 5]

Place close to MOSFETs T13/T14

internal pull-up @ EN-pin

D | D
C | C
B | B
A | A

## Tools for Humanity GmbH

# Battery PCB

## Changelog.SchDoc

## Title

A4 | Variant: B

Changelog:
1.0
- initial release
1.1
- SPI-Flash added (IC3)
- Debug connector X3 added
- L1 replaced by WE-XHMI 74439358022 for f_S = 0.8 MHz instead of 1.2 MHz in order to increase efficiency
- R52: 110k -> 137k
- Update footprint of TPS65987D
- R56: 110k -> 10k
- R54, R55: 10k -> 1k8
- Redcubes X3, X5 added for mechanical mounting
- R1: 12k7 -> 10k
- R2: 10k -> 110k
2.0
- T2, T4, T5, C37, R57, R27, R29, R34, R43, R46, R47 removed
- R42: 220k -> 110k
- T2, R27 added
- R51: 330k -> 110k
- R50: 110k -> 330k
- Ferrit L16 added
- Battery monitor BQ76952 added
- STM32F302RBT6 replaced by STM32L071KZU6
- X4: 61200821621 -> 62200821121
- IC3: MX25L8006EM1I-12G -> MX25L8006EZUI-12G (USON)
- X1: 632723300011 -> DX07S024WJ1
- Temperatur sensor TMP1075 added
- L1: 74439358022 -> 744771002
- Battery undervoltage and overvoltage protection added
- EMC filters added to TYPE_C_CC1/2 and TYPE_C_D_N/P
- R3, R4, R5, R10, R22, R23, R24, R40 removed
- R9: n.m. -> 0R
3.0
- BQ25713 replaced by BQ24780S
- Battery monitor removed
- Battery over-/undervoltage protection removed
- R93, R94 increased from 1k8 to 10k for SMBus specification 4.0
- Battery monitor added
- Battery over-/undervoltage protection added
- Single wire UART interface added
- R7, R37: 10 mR -> 5 mR for reduction of power losses
- L16: 74279252 -> 742792410 for reduced power losses
- Fuse F1 removed
- H4 removed
- Testpoints TP1...5 added
- USB Type C connector X1 replaced by 5 pin socket header
- R9 removed
- Comparator in UVLO circuit replaced
4.1
- X1 replaced by USB Type C receptacle
- T6, T7 replaced by NPN transistor
- R34, R88: 10M -> 1M
- R46, R89: 4M7 -> 470k
4.2
- Testpoints added
- Pads for connection of temperature sensor added
5.0
- STM32L071 replaced by STM32G071
- USB PD controller TPS65987DDHRSHR, Flash and Debug-Connector removed
- IADP and IDCHG of BQ24780 connected to STM32
- R217: 0R -> 10k
- RST_SHUT of BQ76952 connected to STM32
- User button added
- Second NTC connection added
- Red/green status LED replaced by 3 white LEDs
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

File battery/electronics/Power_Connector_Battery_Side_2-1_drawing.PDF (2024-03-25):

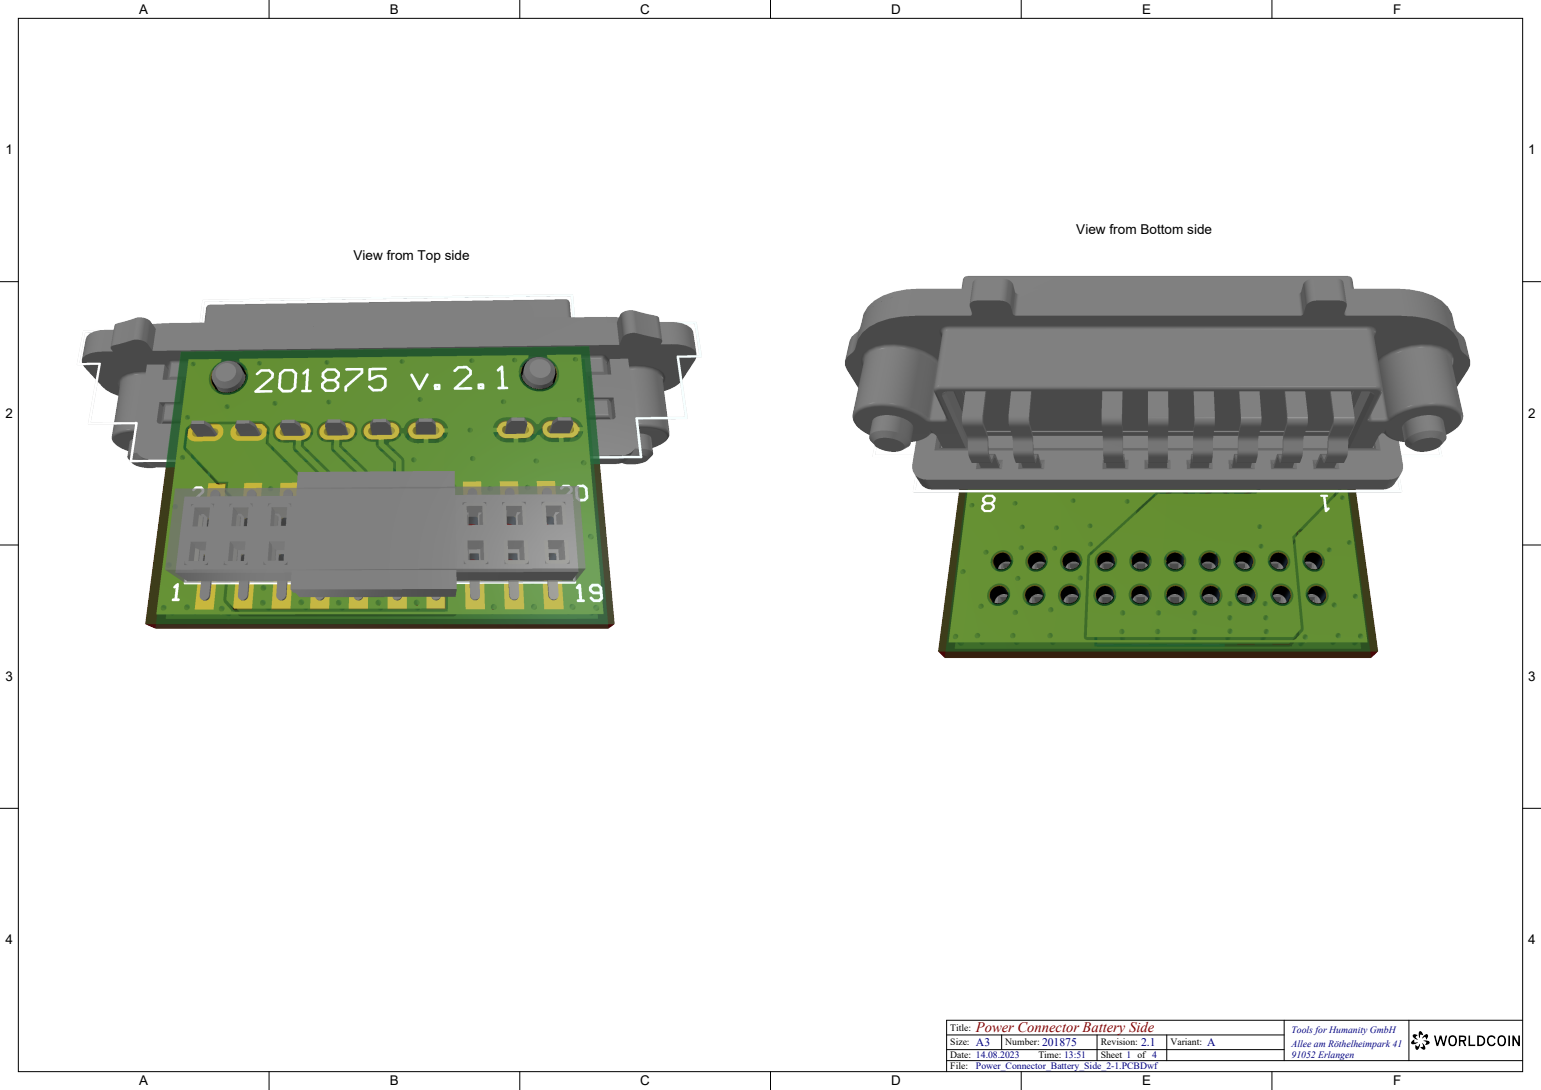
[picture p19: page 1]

View from Bottom side

View from Top side

Title: Power Connector Battery Side
Size: A3
Date: 14.08.2023
File: Power_Connector_Battery_Side_2-1.PCBDwf

Tools for Humanity GmbH
Allee am Röthelheimpark 41
91052 Erlangen

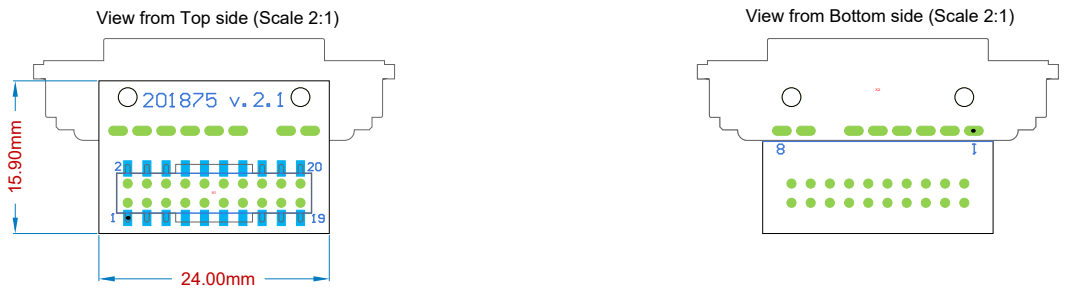
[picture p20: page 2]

View from Top side (Scale 2:1)

View from Bottom side (Scale 2:1)



IPC class | 2
Material | FR4 (Tg 150)
Surface finish | chemical gold (ENIG)
Minimum track space | 150 µm
Minimum drills | 0.2 mm
Solder stop | both sides black
Marking print | both sides white
Lead free marking | yes
Production date marking | yes
Mechanical treatment (panel only) | scored
Via type | tented
Qualification and performance specification | IPC-6012
Material compliance | All materials must be RoHS compliant
Total board thickness | 1.55 mm ± 10 %
Laminate material specification | IPC-4101
Finished hole sizes specification | IPC-2222
Impedance control | None
Electrical testing specification | IPC-9252
Cleanliness requirements | IPC-5704

Thickness | 120 µm
Pad size reduction | 10 %

Requirements for soldering and assembly | IPC J-STD-001
Requirements for inspection | IPC-A-610

Assembled PCB SAP numbers

Variant | SAP number
2.1.A | 201869


View from Top side (Scale 1:1)

FID1 | FID3

FID2

View from Bottom side (Scale 1:1)

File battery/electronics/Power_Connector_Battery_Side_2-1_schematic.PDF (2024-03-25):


Changelog:
- initial release
- SMBUS_SCL connected to GND for unbiased HOST_PRESENT GND connection
- Project renamed from "Battery_Connector_UEBK-30257" to
"Power_Connector_Battery_Side" for less confusion with Orb side connector
PCB
- Old project number replaced by SAP number
- New connectors, new spacers, new PCB outline
- PCB shortend by 0.2 mm to match recommendation in datasheet of connector
YJ-FDC25008-00

7 | 8 | SMC
9 | 10 | SMD_SINGLE_WIRE_CAN_3V3
11 | 12 | HOST_PRESENT_3V3
13 | 14
15 | 16
17 | 18
19 | 20

Power Connector Battery Side
Title

Tools for Humanity GmbH

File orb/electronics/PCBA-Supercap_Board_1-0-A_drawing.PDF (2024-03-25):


Tools for Humanity GmbH
Allee am Röthelheimpark 41
91052 Erlangen


View from Top side (Scale 2:1)

View from Bottom side (Scale 2:1)



IPC class | 2
Material | FR4 (Tg 150)
Surface finish | chemical gold (ENIG)
Minimum track space | 150 µm
Minimum drills | 0.3 mm
Solder stop | both sides black
Marking print | both sides white
Lead free marking | yes
Production date marking | yes
Mechanical treatment (panel only) | milled with perforated bridges
Via type | tented
Qualification and performance specification | IPC-6012
Material compliance | All materials must be RoHS compliant
Total board thickness | 1.69 mm ± 10 %
Laminate material specification | IPC-4101
Finished hole sizes specification | IPC-2222
Impedance control | None
Electrical testing specification | IPC-9252
Cleanliness requirements | IPC-5704

Thickness | 120 µm
Pad size reduction | 10 %

Requirements for soldering and assembly | IPC J-STD-001
Requirements for inspection | IPC-A-610

Assembled PCB SAP numbers

Variant | SAP number
1.0.A | 201659


View from Top side (Scale 1:1)

View from Bottom side (Scale 1:1)

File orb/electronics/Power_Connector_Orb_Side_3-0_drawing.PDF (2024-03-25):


View from Bottom side

View from Top side

Title: Power Connector Orb Side
Size: A3
Date: 03.07.2023
File: Power_Connector_Orb_Side_3-0.PCBDwf

Tools for Humanity GmbH
Allee am Röthelheimpark 41
91052 Erlangen


View from Top side (Scale 2:1)

View from Bottom side (Scale 2:1)



IPC class | 2
Material | FR4 (Tg 150)
Surface finish | chemical gold (ENIG)
Minimum track space | 150 µm
Minimum drills | 0.3 mm
Solder stop | both sides black
Marking print | both sides white
Lead free marking | yes
Production date marking | yes
Mechanical treatment (panel only) | milled with perforated bridges
Via type | tented
Qualification and performance specification | IPC-6012
Material compliance | All materials must be RoHS compliant
Total board thickness | 1.55 mm ± 10 %
Laminate material specification | IPC-4101
Finished hole sizes specification | IPC-2222
Impedance control | None
Electrical testing specification | IPC-9252
Cleanliness requirements | IPC-5704

Thickness | 120 µm
Pad size reduction | 10 %

Requirements for soldering and assembly | IPC J-STD-001
Requirements for inspection | IPC-A-610

Assembled PCB SAP numbers

Variant | SAP number
3.0.A | 201709


View from Top side (Scale 1:1)

View from Bottom side (Scale 1:1)

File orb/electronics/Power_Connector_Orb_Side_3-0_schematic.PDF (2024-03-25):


Changelog:
- PCB outline changed
- 2 holes removed
- Project number replaced by Aligni number 63-00018

- HOST_PRESENT connected to SMBUS_SCL for unbiased GND
connection patch

- Project renamed from "63-00018_Battery_Connector_UEBK-30256"
to "Power_Connector_Orb_Side" for less confusion with Battery
side connector PCB
- Aligni number replaced by SAP number
- X1: UEBK-30256 -> todo
- New PCB outline
- SPACER1, SPACER2: 9774027151 -> 9774010151
- Fiducals removed
- Dimensions of wirepads X2...X5 changed
- Host-present bridged at connector X1

Power Connector Orb Side
Title

Tools for Humanity GmbH


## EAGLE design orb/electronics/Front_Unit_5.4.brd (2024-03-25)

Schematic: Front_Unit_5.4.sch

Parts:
C1, C2, C4, C12, C13, C14, C16, C20, C21, C22, C25, C27, C28, C30, C32, C33, C42, C43: 4u7 50V; C1210
C3, C5, C6, C7, C8, C9, C24, C26, C38: 1u 25V; C0805
C10: 27p 50V; C0603
C11: C-EU-C0603; C0603; VOLTAGE 50.0 V
C15: 100p 50V; C0603
C17, C18, C19, C23, C34, C37, C39, C40, C41, C44, C48, C49, C50, C51, C52, C53, C57, C59: 100n 50V; C0603
C45, C46, C47, C60, C78: 22u 10V; C0805
C54: n.m.; C1206; VOLTAGE 6V3
C55, C56: 22u 16V; C1206
C58: 4u7 16V; C0805
C61, C100, C102, C104, C106, C108, C110, C112, C114, C116, C118, C120, C122, C124, C126, C128, C130, C132, C134, C136, C138, C140, C142, C144, C146, C148, C150, C152, C154, C156, C158, C162, C164, C166, C168, C170, C172, C174, C176, C178, C180, C182, C184, C186, C188, C190, C192, C194, C196, C198, C200, C202, C204, C206, C208, C210, C212, C214, C216, C218, C220, C222, C224, C226, C228, C230, C232, C234, C236, C238, C240, C242, C244, C246, C248, C250, C252, C254, C256, C258, C260, C262, C264, C266, C270, C272, C280, C282, C284, C286, C288, C290, C292, C294, C296, C298, C300, C302, C304, C306, C308, C310, C312, C314, C316, C318, C320, C322, C324, C326, C328, C330, C332: 1u 25V; C0603
C101, C103, C105, C107, C109, C111, C113, C115, C117, C119, C121, C123, C125, C127, C129, C131, C133, C135, C137, C139, C141, C143, C145, C147, C149, C151, C153, C155, C157, C159, C165, C167, C169, C171, C173, C175, C177, C179, C181, C183, C185, C187, C189, C191, C193, C195, C197, C199, C201, C203, C205, C207, C209, C211, C213, C215, C217, C219, C221, C223, C225, C227, C229, C231, C233, C235, C237, C239, C241, C243, C245, C247, C249, C251, C253, C255, C257, C259, C261, C263, C265, C281, C283, C285, C287, C289, C291, C293, C295, C297, C299, C301, C303, C305, C307, C309, C311, C313, C315, C317, C319, C321, C323, C325, C327, C329, C331: C-EU-C0603; C0603; VOLTAGE 25.0 V
D1: 150060RS75000; WL-SMCW_0603_WE
D2: 150060GS75000; WL-SMCW_0603_WE
D100, D101, D102, D103, D104, D105, D106, D107, D108, D109, D110, D111, D112: LZ1-00R302; LZ1_SMALL_LEDENGIN
D200, D201, D202, D203, D204, D205, D206, D207, D208, D209, D210, D211, D212, D213, D214, D215, D250, D251, D252, D253, D254, D255, D256, D257, D258, D259, D260, D261, D262, D263, D264, D265: SST-10-IRD-B50-T850; B50_LUMINUS
D300, D301, D302, D303, D304, D305, D306, D307, D308, D309, D310, D311, D312, D313, D314, D315, D350, D351, D352, D353, D354, D355, D356, D357, D358, D359, D360, D361, D362, D363, D364, D365: SST-10-IRD-B50-S940; B50_LUMINUS
IC1, IC2, IC8, IC10, IC13: UCC27517DBV; DBV0005A_TI
IC3, IC4, IC5: LM393BIDSG; DSG0008A_WSON_TI_NO_VIA
IC7: VL53L1CBV0FY/1; VL53L1X_STM
IC9: SN74LVC112ADGV; TVSOP-16_TI
IC12, IC14, IC16, IC17, IC18, IC19, IC20: 824001; SOT23-6L_WE
IC15: TMP1075DGK; S-PDSO-G8_DGK_VSSOP_TI
IC24: TMP112NAIDRL; DRL0006A_TI
IC25: BU27030NUC; WSON008X2120_ROHM
IC31: TLV71328PDBV; R-PDSO-G5_DBV_TI
IC100, IC101, IC102, IC103, IC104, IC105, IC106, IC107, IC108, IC109, IC110, IC111, IC112, IC113, IC114, IC115, IC116, IC117, IC118, IC119, IC120, IC121, IC122, IC123, IC124, IC125, IC126, IC127, IC128, IC129, IC130, IC131, IC132, IC133, IC134, IC135, IC136, IC137, IC138, IC139, IC140, IC141, IC142, IC143, IC144, IC145, IC146, IC147, IC148, IC149, IC150, IC151, IC152, IC153, IC154, IC155, IC156, IC157, IC158, IC159, IC160, IC161, IC162, IC163, IC164, IC165, IC166, IC167, IC168, IC169, IC170, IC171, IC172, IC173, IC174, IC175, IC176, IC177, IC178, IC179, IC180, IC181, IC182, IC183, IC184, IC185, IC186, IC187, IC188, IC189, IC190, IC191, IC192, IC193, IC194, IC195, IC196, IC197, IC198, IC199, IC200, IC201, IC202, IC203, IC204, IC205, IC206, IC207, IC208, IC209, IC210, IC211, IC212, IC213, IC214, IC215, IC216, IC217, IC218, IC219, IC220, IC221, IC222, IC223, IC224, IC225, IC226, IC227, IC228, IC229, IC230, IC231, IC232, IC233, IC234, IC235, IC236, IC237, IC238, IC239, IC240, IC241, IC242, IC243, IC244, IC245, IC246, IC247, IC248, IC249, IC250, IC251, IC252, IC253, IC254, IC255, IC256, IC257, IC258, IC259, IC260, IC261, IC262, IC263, IC264, IC265, IC266, IC267, IC268, IC269, IC270, IC271, IC272, IC273, IC274, IC275, IC276, IC277, IC278, IC279, IC280, IC281, IC282, IC283, IC284, IC285, IC286, IC287, IC288, IC289, IC290, IC291, IC292, IC293, IC294, IC295, IC296, IC297, IC298, IC299, IC300, IC301, IC302, IC303, IC304, IC305, IC306, IC307, IC308, IC309, IC310, IC311, IC312, IC313, IC314, IC315, IC316, IC317, IC318, IC319, IC320, IC321, IC322, IC323, IC324, IC325, IC326, IC327, IC328, IC329, IC330, IC331, IC332: SK6805-EC15; SK6805-EC_IPIXEL
L9: 74279269; FERRIT_0603_WIDE_BAND_WUERTH
L11, L14: 742792097; FERRIT_0805_WUERTH
PS1, PS2, PS3, PS4, PS5, PS6: PASSERMARKE
R1, R9, R16, R19, R26, R27, R28, R38, R44, R47, R49, R72, R76, R78, R79: 0R; R0603
R2, R31, R40, R67: 10k; R0603
R3, R4, R5, R6, R10, R11, R12, R13, R60, R64: 56k; R0603
R7, R83, R84: 15R 0W75; R1210
R8, R15, R20, R22, R25, R29, R34, R35, R43, R46, R52, R57, R66, R69, R73, R75: 3R9 0W75; R1210
R17: 91k; R0603
R18: 27k; R0603
R21, R23, R24, R30, R32, R33, R37, R39, R54, R55, R56, R59, R80, R81, R82: 27R; R0603
R62: 1k1; R0603
R70, R71: R-EU-R0603; R0603
R87: 100R; R0603
SW1: ATE-1C-V; ATE-1C_DIPTRONICS
T2, T3, T6, T7, T10: PMV30ENEA; SOT-23_NXP
T8: NX7002AK; SOT-23_NXP
TP1: GND; TESTPAD_ROUND_1.5MM
TP2: +PVCC; TESTPAD_ROUND_1.5MM
TP3, TP4, TP5, TP6, TP7, TP8, TP9, TP10, TP11, TP12, TP14, TP15, TP16, TP17, TP18, TP19, TP20, TP21, TP22, TP23: TESTPOINT_ROUND_1.5MM; TESTPAD_ROUND_1.5MM
TP13: SAFETY_SHDN_RST; TESTPAD_ROUND_1.5MM
X1, X2: MEC6-120-02-L-DV-A; MEC6-120-02
X3: DF37NC-30DS-0.4V
X4: 687112182122; 687112182122_WUERTH
X5: AXE530127; AXE530127_PANASONIC

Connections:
!SAFETY_SHDN: C15.2, IC9.15 (!CLR), R24.2, R31.1, TP11.TP
$N200: IC325.3 (DOUT), IC326.1 (DIN)
$N201: IC327.3 (DOUT), IC328.1 (DIN)
$N202: IC329.3 (DOUT), IC330.1 (DIN)
$N203: IC331.3 (DOUT), IC332.1 (DIN)
+1V2: C46.1, X1.20, X3.27
+1V8: C37.1, C44.1, C45.1, C49.1, IC12.5 (VBUS), IC16.5 (VBUS), IC18.5 (VBUS), R16.2, X1.18, X3.28
+2V8: C50.1, IC19.5 (VBUS), X1.16
+2V8_LDO: C47.1, L14.1, X3.21
+3V3: C11.1, C15.1, C39.1, C51.1, D1.A, D2.A, IC14.5 (VBUS), IC20.5 (VBUS), L9.1, R17.2, R19.1, R26.2, R27.2, R28.2, R31.2, R40.2, R60.2, R64.2, R72.1, R76.2, R79.2, TP3.TP, X1.14
+3V6: C54.1, C55.1, C56.1, L11.2, X1.22, X5.1, X5.2, X5.3, X5.4, X5.6, X5.8
+5V: C48.1, C100.1, C101.1, C102.1, C103.1, C104.1, C105.1, C106.1, C107.1, C108.1, C109.1, C110.1, C111.1, C112.1, C113.1, C114.1, C115.1, C116.1, C117.1, C118.1, C119.1, C120.1, C121.1, C122.1, C123.1, C124.1, C125.1, C126.1, C127.1, C128.1, C129.1, C130.1, C131.1, C132.1, C133.1, C134.1, C135.1, C136.1, C137.1, C138.1, C139.1, C140.1, C141.1, C142.1, C143.1, C144.1, C145.1, C146.1, C147.1, C148.1, C149.1, C150.1, C151.1, C152.1, C153.1, C154.1, C155.1, C156.1, C157.1, C158.1, C159.1, C162.1, C164.1, C165.1, C166.1, C167.1, C168.1, C169.1, C170.1, C171.1, C172.1, C173.1, C174.1, C175.1, C176.1, C177.1, C178.1, C179.1, C180.1, C181.1, C182.1, C183.1, C184.1, C185.1, C186.1, C187.1, C188.1, C189.1, C190.1, C191.1, C192.1, C193.1, C194.1, C195.1, C196.1, C197.1, C198.1, C199.1, C200.1, C201.1, C202.1, C203.1, C204.1, C205.1, C206.1, C207.1, C208.1, C209.1, C210.1, C211.1, C212.1, C213.1, C214.1, C215.1, C216.1, C217.1, C218.1, C219.1, C220.1, C221.1, C222.1, C223.1, C224.1, C225.1, C226.1, C227.1, C228.1, C229.1, C230.1, C231.1, C232.1, C233.1, C234.1, C235.1, C236.1, C237.1, C238.1, C239.1, C240.1, C241.1, C242.1, C243.1, C244.1, C245.1, C246.1, C247.1, C248.1, C249.1, C250.1, C251.1, C252.1, C253.1, C254.1, C255.1, C256.1, C257.1, C258.1, C259.1, C260.1, C261.1, C262.1, C263.1, C264.1, C265.1, C266.1, C270.1, C272.1, C280.1, C281.1, C282.1, C283.1, C284.1, C285.1, C286.1, C287.1, C288.1, C289.1, C290.1, C291.1, C292.1, C293.1, C294.1, C295.1, C296.1, C297.1, C298.1, C299.1, C300.1, C301.1, C302.1, C303.1, C304.1, C305.1, C306.1, C307.1, C308.1, C309.1, C310.1, C311.1, C312.1, C313.1, C314.1, C315.1, C316.1, C317.1, C318.1, C319.1, C320.1, C321.1, C322.1, C323.1, C324.1, C325.1, C326.1, C327.1, C328.1, C329.1, C330.1, C331.1, C332.1, IC17.5 (VBUS), IC100.2 (VDD), IC101.2 (VDD), IC102.2 (VDD), IC103.2 (VDD), IC104.2 (VDD), IC105.2 (VDD), IC106.2 (VDD), IC107.2 (VDD), IC108.2 (VDD), IC109.2 (VDD), IC110.2 (VDD), IC111.2 (VDD), IC112.2 (VDD), IC113.2 (VDD), IC114.2 (VDD), IC115.2 (VDD), IC116.2 (VDD), IC117.2 (VDD), IC118.2 (VDD), IC119.2 (VDD), IC120.2 (VDD), IC121.2 (VDD), IC122.2 (VDD), IC123.2 (VDD), IC124.2 (VDD), IC125.2 (VDD), IC126.2 (VDD), IC127.2 (VDD), IC128.2 (VDD), IC129.2 (VDD), IC130.2 (VDD), IC131.2 (VDD), IC132.2 (VDD), IC133.2 (VDD), IC134.2 (VDD), IC135.2 (VDD), IC136.2 (VDD), IC137.2 (VDD), IC138.2 (VDD), IC139.2 (VDD), IC140.2 (VDD), IC141.2 (VDD), IC142.2 (VDD), IC143.2 (VDD), IC144.2 (VDD), IC145.2 (VDD), IC146.2 (VDD), IC147.2 (VDD), IC148.2 (VDD), IC149.2 (VDD), IC150.2 (VDD), IC151.2 (VDD), IC152.2 (VDD), IC153.2 (VDD), IC154.2 (VDD), IC155.2 (VDD), IC156.2 (VDD), IC157.2 (VDD), IC158.2 (VDD), IC159.2 (VDD), IC160.2 (VDD), IC161.2 (VDD), IC162.2 (VDD), IC163.2 (VDD), IC164.2 (VDD), IC165.2 (VDD), IC166.2 (VDD), IC167.2 (VDD), IC168.2 (VDD), IC169.2 (VDD), IC170.2 (VDD), IC171.2 (VDD), IC172.2 (VDD), IC173.2 (VDD), IC174.2 (VDD), IC175.2 (VDD), IC176.2 (VDD), IC177.2 (VDD), IC178.2 (VDD), IC179.2 (VDD), IC180.2 (VDD), IC181.2 (VDD), IC182.2 (VDD), IC183.2 (VDD), IC184.2 (VDD), IC185.2 (VDD), IC186.2 (VDD), IC187.2 (VDD), IC188.2 (VDD), IC189.2 (VDD), IC190.2 (VDD), IC191.2 (VDD), IC192.2 (VDD), IC193.2 (VDD), IC194.2 (VDD), IC195.2 (VDD), IC196.2 (VDD), IC197.2 (VDD), IC198.2 (VDD), IC199.2 (VDD), IC200.2 (VDD), IC201.2 (VDD), IC202.2 (VDD), IC203.2 (VDD), IC204.2 (VDD), IC205.2 (VDD), IC206.2 (VDD), IC207.2 (VDD), IC208.2 (VDD), IC209.2 (VDD), IC210.2 (VDD), IC211.2 (VDD), IC212.2 (VDD), IC213.2 (VDD), IC214.2 (VDD), IC215.2 (VDD), IC216.2 (VDD), IC217.2 (VDD), IC218.2 (VDD), IC219.2 (VDD), IC220.2 (VDD), IC221.2 (VDD), IC222.2 (VDD), IC223.2 (VDD), IC224.2 (VDD), IC225.2 (VDD), IC226.2 (VDD), IC227.2 (VDD), IC228.2 (VDD), IC229.2 (VDD), IC230.2 (VDD), IC231.2 (VDD), IC232.2 (VDD), IC233.2 (VDD), IC234.2 (VDD), IC235.2 (VDD), IC236.2 (VDD), IC237.2 (VDD), IC238.2 (VDD), IC239.2 (VDD), IC240.2 (VDD), IC241.2 (VDD), IC242.2 (VDD), IC243.2 (VDD), IC244.2 (VDD), IC245.2 (VDD), IC246.2 (VDD), IC247.2 (VDD), IC248.2 (VDD), IC249.2 (VDD), IC250.2 (VDD), IC251.2 (VDD), IC252.2 (VDD), IC253.2 (VDD), IC254.2 (VDD), IC255.2 (VDD), IC256.2 (VDD), IC257.2 (VDD), IC258.2 (VDD), IC259.2 (VDD), IC260.2 (VDD), IC261.2 (VDD), IC262.2 (VDD), IC263.2 (VDD), IC264.2 (VDD), IC265.2 (VDD), IC266.2 (VDD), IC267.2 (VDD), IC268.2 (VDD), IC269.2 (VDD), IC270.2 (VDD), IC271.2 (VDD), IC272.2 (VDD), IC273.2 (VDD), IC274.2 (VDD), IC275.2 (VDD), IC276.2 (VDD), IC277.2 (VDD), IC278.2 (VDD), IC279.2 (VDD), IC280.2 (VDD), IC281.2 (VDD), IC282.2 (VDD), IC283.2 (VDD), IC284.2 (VDD), IC285.2 (VDD), IC286.2 (VDD), IC287.2 (VDD), IC288.2 (VDD), IC289.2 (VDD), IC290.2 (VDD), IC291.2 (VDD), IC292.2 (VDD), IC293.2 (VDD), IC294.2 (VDD), IC295.2 (VDD), IC296.2 (VDD), IC297.2 (VDD), IC298.2 (VDD), IC299.2 (VDD), IC300.2 (VDD), IC301.2 (VDD), IC302.2 (VDD), IC303.2 (VDD), IC304.2 (VDD), IC305.2 (VDD), IC306.2 (VDD), IC307.2 (VDD), IC308.2 (VDD), IC309.2 (VDD)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
+PVCC: C1.1, C2.1, C4.1, C12.1, C13.1, C14.1, C16.1, C20.1, C21.1, C22.1, C25.1, C27.1, C28.1, C30.1, C32.1, C33.1, C41.1, C42.1, C43.1, R7.2, R8.2, R15.2, R20.2, R22.2, R25.2, R29.2, R34.2, R35.2, R43.2, R46.2, R52.2, R57.2, R66.2, R69.2, R73.2, R75.2, R83.2, R84.2, TP2.TP, X2.02 (2), X2.04 (4), X2.06 (6), X2.08 (8)
+VBAT: R1.1, R9.1, R38.1, R44.1, R78.1, TP4.TP, X1.30
CAM1_RGB_!PWDN_1V8: IC12.3 (I/O2), X1.08 (8), X3.26
CAM1_RGB_CLK_N: X1.05 (5), X3.5
CAM1_RGB_CLK_P: X1.03 (3), X3.4
CAM1_RGB_D0_N: X1.11, X3.8
CAM1_RGB_D0_P: X1.09 (9), X3.7
CAM1_RGB_D1_N: X1.17, X3.11
CAM1_RGB_D1_P: X1.15, X3.10
CAM1_RGB_I2C_SCL_1V8: IC12.4 (I/O3), X1.12, X3.2
CAM1_RGB_I2C_SDA_1V8: IC12.6 (I/O4), X1.10, X3.1
CAM1_RGB_MCLK_1V8: IC12.1 (I/O1), X1.04 (4), X3.24
CAM3_TOF_!PWDN!_1V8: IC18.6 (I/O4), X2.16, X5.30
CAM3_TOF_CLK_N: X2.36, X5.23
CAM3_TOF_CLK_P: X2.38, X5.21
CAM3_TOF_D0_N: X2.27, X5.17
CAM3_TOF_D0_P: X2.29, X5.15
CAM3_TOF_D1_N: X2.30, X5.29
CAM3_TOF_D1_P: X2.32, X5.27
CAM3_TOF_I2C_SCL_1V8: IC18.1 (I/O1), X2.22, X5.24
CAM3_TOF_I2C_SDA_1V8: IC18.3 (I/O2), X2.20, X5.26
CAM3_TOF_MCLK_1V8: IC18.4 (I/O3), R47.1, X2.33
COPY_SIG_1: IC101.3 (DOUT), IC102.1 (DIN)
COPY_SIG_2: IC102.3 (DOUT), IC103.1 (DIN)
FET_DRV_!EN: IC1.4 (IN-), IC2.4 (IN-), IC8.4 (IN-), IC10.4 (IN-), IC13.4 (IN-), T8.3 (D)
FU_I2C_TEMP_SCL_3V3: IC14.4 (I/O3), R32.2, R39.2, R82.2, TP22.TP, X1.29
FU_I2C_TEMP_SDA_3V3: IC14.3 (I/O2), R30.2, R33.2, R81.2, TP23.TP, X1.31
FU_PVCC_EN_3V3: IC14.6 (I/O4), R55.2, R60.1, R62.1, T8.1 (G), TP10.TP, X1.27
FU_TAMPER_SWITCH: SW1.3 (NO), SW1.4 (NO), X1.34
GND: C1.2, C2.2, C3.2, C4.2, C5.2, C6.2, C7.2, C8.2, C9.2, C10.2, C12.2, C13.2, C14.2, C16.2, C17.2, C18.2, C19.2, C20.2, C21.2, C22.2, C23.2, C24.2, C25.2, C26.2, C27.2, C28.2, C30.2, C32.2, C33.2, C34.2, C37.2, C38.2, C39.2, C40.2, C41.2, C42.2, C43.2, C44.2, C45.2, C46.2, C47.2, C48.2, C49.2, C50.2, C51.2, C52.2, C53.2, C54.2, C55.2, C56.2, C57.2, C58.2, C59.2, C60.2, C61.2, C78.2, C100.2, C101.2, C102.2, C103.2, C104.2, C105.2, C106.2, C107.2, C108.2, C109.2, C110.2, C111.2, C112.2, C113.2, C114.2, C115.2, C116.2, C117.2, C118.2, C119.2, C120.2, C121.2, C122.2, C123.2, C124.2, C125.2, C126.2, C127.2, C128.2, C129.2, C130.2, C131.2, C132.2, C133.2, C134.2, C135.2, C136.2, C137.2, C138.2, C139.2, C140.2, C141.2, C142.2, C143.2, C144.2, C145.2, C146.2, C147.2, C148.2, C149.2, C150.2, C151.2, C152.2, C153.2, C154.2, C155.2, C156.2, C157.2, C158.2, C159.2, C162.2, C164.2, C165.2, C166.2, C167.2, C168.2, C169.2, C170.2, C171.2, C172.2, C173.2, C174.2, C175.2, C176.2, C177.2, C178.2, C179.2, C180.2, C181.2, C182.2, C183.2, C184.2, C185.2, C186.2, C187.2, C188.2, C189.2, C190.2, C191.2, C192.2, C193.2, C194.2, C195.2, C196.2, C197.2, C198.2, C199.2, C200.2, C201.2, C202.2, C203.2, C204.2, C205.2, C206.2, C207.2, C208.2, C209.2, C210.2, C211.2, C212.2, C213.2, C214.2, C215.2, C216.2, C217.2, C218.2, C219.2, C220.2, C221.2, C222.2, C223.2, C224.2, C225.2, C226.2, C227.2, C228.2, C229.2, C230.2, C231.2, C232.2, C233.2, C234.2, C235.2, C236.2, C237.2, C238.2, C239.2, C240.2, C241.2, C242.2, C243.2, C244.2, C245.2, C246.2, C247.2, C248.2, C249.2, C250.2, C251.2, C252.2, C253.2, C254.2, C255.2, C256.2, C257.2, C258.2, C259.2, C260.2, C261.2, C262.2, C263.2, C264.2, C265.2, C266.2, C270.2, C272.2, C280.2, C281.2, C282.2, C283.2, C284.2, C285.2, C286.2, C287.2, C288.2, C289.2, C290.2, C291.2, C292.2, C293.2, C294.2, C295.2, C296.2, C297.2, C298.2, C299.2, C300.2, C301.2, C302.2, C303.2, C304.2, C305.2, C306.2, C307.2, C308.2, C309.2, C310.2, C311.2, C312.2, C313.2, C314.2, C315.2, C316.2, C317.2, C318.2, C319.2, C320.2, C321.2, C322.2, C323.2, C324.2, C325.2, C326.2, C327.2, C328.2, C329.2, C330.2, C331.2, C332.2, D100.5, D101.5, D102.5, D103.5, D104.5, D105.5, D106.5, D107.5, D108.5, D109.5, D110.5, D111.5, D112.5, D200.NC, D201.NC, D202.NC, D203.NC, D204.NC, D205.NC, D206.NC, D207.NC, D208.NC, D209.NC, D210.NC, D211.NC, D212.NC, D213.NC, D214.NC, D215.NC, D250.NC, D251.NC, D252.NC, D253.NC, D254.NC, D255.NC, D256.NC, D257.NC, D258.NC, D259.NC, D260.NC, D261.NC, D262.NC, D263.NC, D264.NC, D265.NC, D300.NC, D301.NC, D302.NC, D303.NC, D304.NC, D305.NC, D306.NC, D307.NC, D308.NC, D309.NC, D310.NC, D311.NC, D312.NC, D313.NC, D314.NC, D315.NC, D350.NC, D351.NC, D352.NC, D353.NC, D354.NC, D355.NC, D356.NC, D357.NC, D358.NC, D359.NC, D360.NC, D361.NC, D362.NC, D363.NC, D364.NC, D365.NC, IC1.2 (GND), IC2.2 (GND), IC3.4 (GND), IC3.PAD (GND), IC4.4 (GND), IC4.6 (-IN), IC4.PAD (GND), IC5.4 (GND), IC5.6 (-IN), IC5.PAD (GND), IC7.2 (AVSSVCSEL), IC7.3 (GND), IC7.4 (GND), IC7.6 (GND), IC7.12 (GND), IC8.2 (GND), IC9.1 (CLK), IC9.2 (K), IC9.3 (J), IC9.8 (GND), IC9.10 (!PRE), IC9.11 (J), IC9.12 (K), IC9.13 (CLK), IC9.14 (!CLR), IC10.2 (GND), IC12.2 (GND), IC13.2 (GND), IC14.2 (GND), IC15.4 (GND), IC15.5 (A2), IC15.6 (A1), IC15.7 (A0), IC16.2 (GND), IC17.2 (GND), IC18.2 (GND), IC19.2 (GND), IC20.2 (GND), IC24.2 (GND), IC24.4 (ADD0), IC25.3 (GND), IC25.PAD (GND), IC31.2 (GND), IC31.4 (GND), IC100.4 (VSS), IC101.4 (VSS), IC102.4 (VSS), IC103.4 (VSS), IC104.4 (VSS), IC105.4 (VSS), IC106.4 (VSS), IC107.4 (VSS), IC108.4 (VSS), IC109.4 (VSS), IC110.4 (VSS), IC111.4 (VSS), IC112.4 (VSS), IC113.4 (VSS), IC114.4 (VSS), IC115.4 (VSS), IC116.4 (VSS), IC117.4 (VSS), IC118.4 (VSS), IC119.4 (VSS), IC120.4 (VSS), IC121.4 (VSS), IC122.4 (VSS), IC123.4 (VSS), IC124.4 (VSS), IC125.4 (VSS), IC126.4 (VSS), IC127.4 (VSS), IC128.4 (VSS), IC129.4 (VSS), IC130.4 (VSS), IC131.4 (VSS), IC132.4 (VSS), IC133.4 (VSS), IC134.4 (VSS)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
HEAT_CAM_ARESET_N_2V8: IC20.4 (I/O3), X2.23, X4.5
HEAT_CAM_FPA_EN_2V8: IC19.6 (I/O4), X2.13, X4.10
HEAT_CAM_MISO_2V8: IC19.1 (I/O1), R87.2, X2.19
HEAT_CAM_MOSI_2V8: IC19.3 (I/O2), X2.17, X4.8
HEAT_CAM_SCLK_2V8: IC19.4 (I/O3), X2.15, X4.9
HEAT_CAM_SCT_NSS_2V8: IC20.6 (I/O4), X2.21, X4.6
unnamed: D306.A, D307.C
unnamed: D350.C, D357.A
unnamed: D304.A, D305.C
unnamed: D314.A, D315.C
unnamed: D313.A, D314.C
unnamed: D312.A, D313.C
unnamed: C57.1, C58.1, IC7.1 (AVDDVCSEL), IC7.11 (AVDD), R2.2, R19.2
unnamed: D311.A, D312.C
unnamed: D303.A, D304.C
unnamed: D302.A, D303.C
unnamed: D301.A, D302.C
unnamed: D300.A, D301.C
unnamed: IC8.5 (OUT), R54.1, TP5.TP
unnamed: R54.2, T6.1 (G)
unnamed: D352.A, D353.C
unnamed: D351.A, D352.C
unnamed: D350.A, D351.C
unnamed: D360.A, D361.C
unnamed: D359.A, D360.C
unnamed: IC1.5 (OUT), R21.1
unnamed: R21.2, T2.1 (G), TP15.TP
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

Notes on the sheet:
RGB CAM + TOF CAM + Heat Cam
Changelog 2.0 - IR LEDs SFH4780S (810nm) replaced by SST-10-IRD-B50-T850 (850nm) and SST-10-IRD-B50-S940 (940nm) - Connector X10 620110131822 -> 68711214522 - CH101 (ultrasonic ToF sensor) added - Boost converter für high current pulsing added - Buck-Boost converter added - Safety shutdown circuit 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
SST-10-IRD-B50-S940: I_f,typ = 3.00V @ 0.75A = 3.35V @ 1.5A<<< = 3.80V @ 2.5A = 5.00V @ 5.0A
SST-10-IRD-B50-T850 I_f,typ = 2.75 V @ 0.1A = 3.20V @ 0.75A = 3.55V @ 1.5A ~2A <<<<< = 4.00V @ 2.5A = 5.20V @ 5.0A
IR LEDs 940 nm 1/2
Safety circuit 1/2
f_CLK = 1 ... 2560 kHz
address: 1001000b
Temperature Sensor
IR LEDs 940 nm 2/2
IR LEDs 850 nm 1/2
LZ1-00R302 I_f,typ = 2.20 V @ 1.0 A
IR LEDs 740 nm
Safety circuit 2/2
open drain outputs @ LM393B
Card edge connector
IR LEDs 850 nm 2/2
IR850_Left(16)
IR940_Left (16)
IR940_Right (16)
IR850_Right(16)
+PVCC = 31.3 V
RGB_RING (224)
RGB_UX_DOT (9)
IR940_2L (10)
IR940_2R (10)
IR940_1L (6)
IR940_1R (6)
IR850_2L (9)
IR850_2R (9)
IR850_1L (7)
IR850_1R (7)
IR740_1 (6)
IR740_2 (7)
IR740 (13) + Temp Sensor
RGB CAM
TOF CAM
Heat Cam
Connector Bridge PCB
Safety Circuit

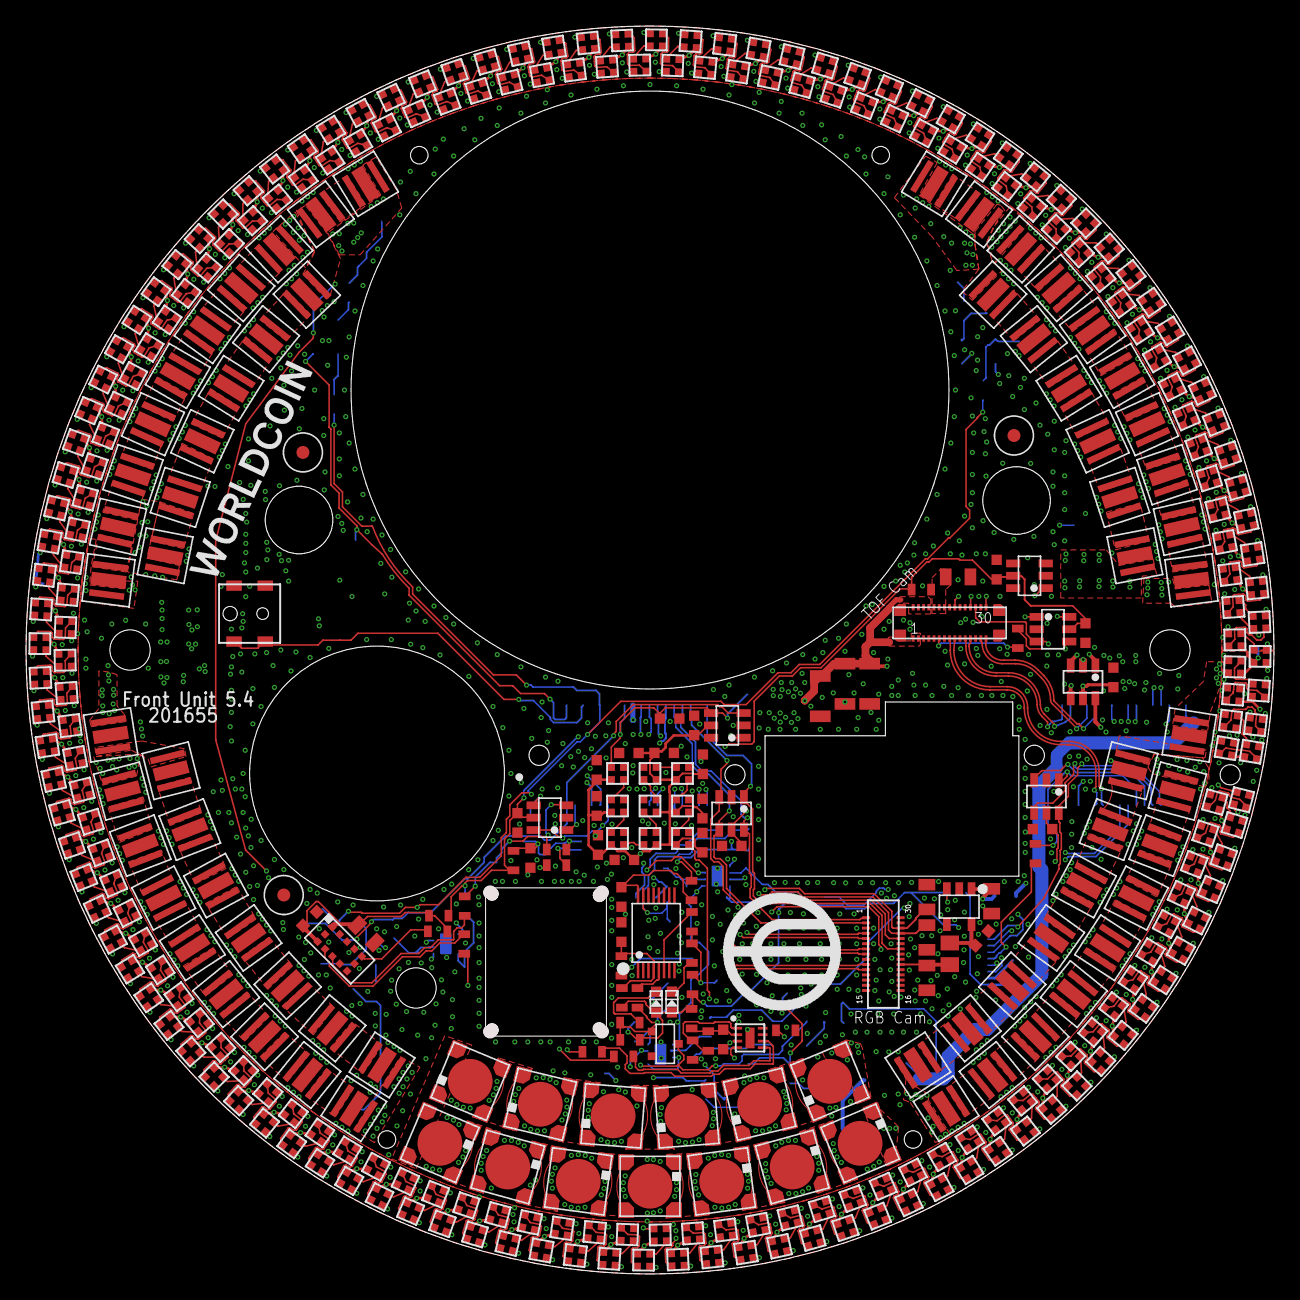
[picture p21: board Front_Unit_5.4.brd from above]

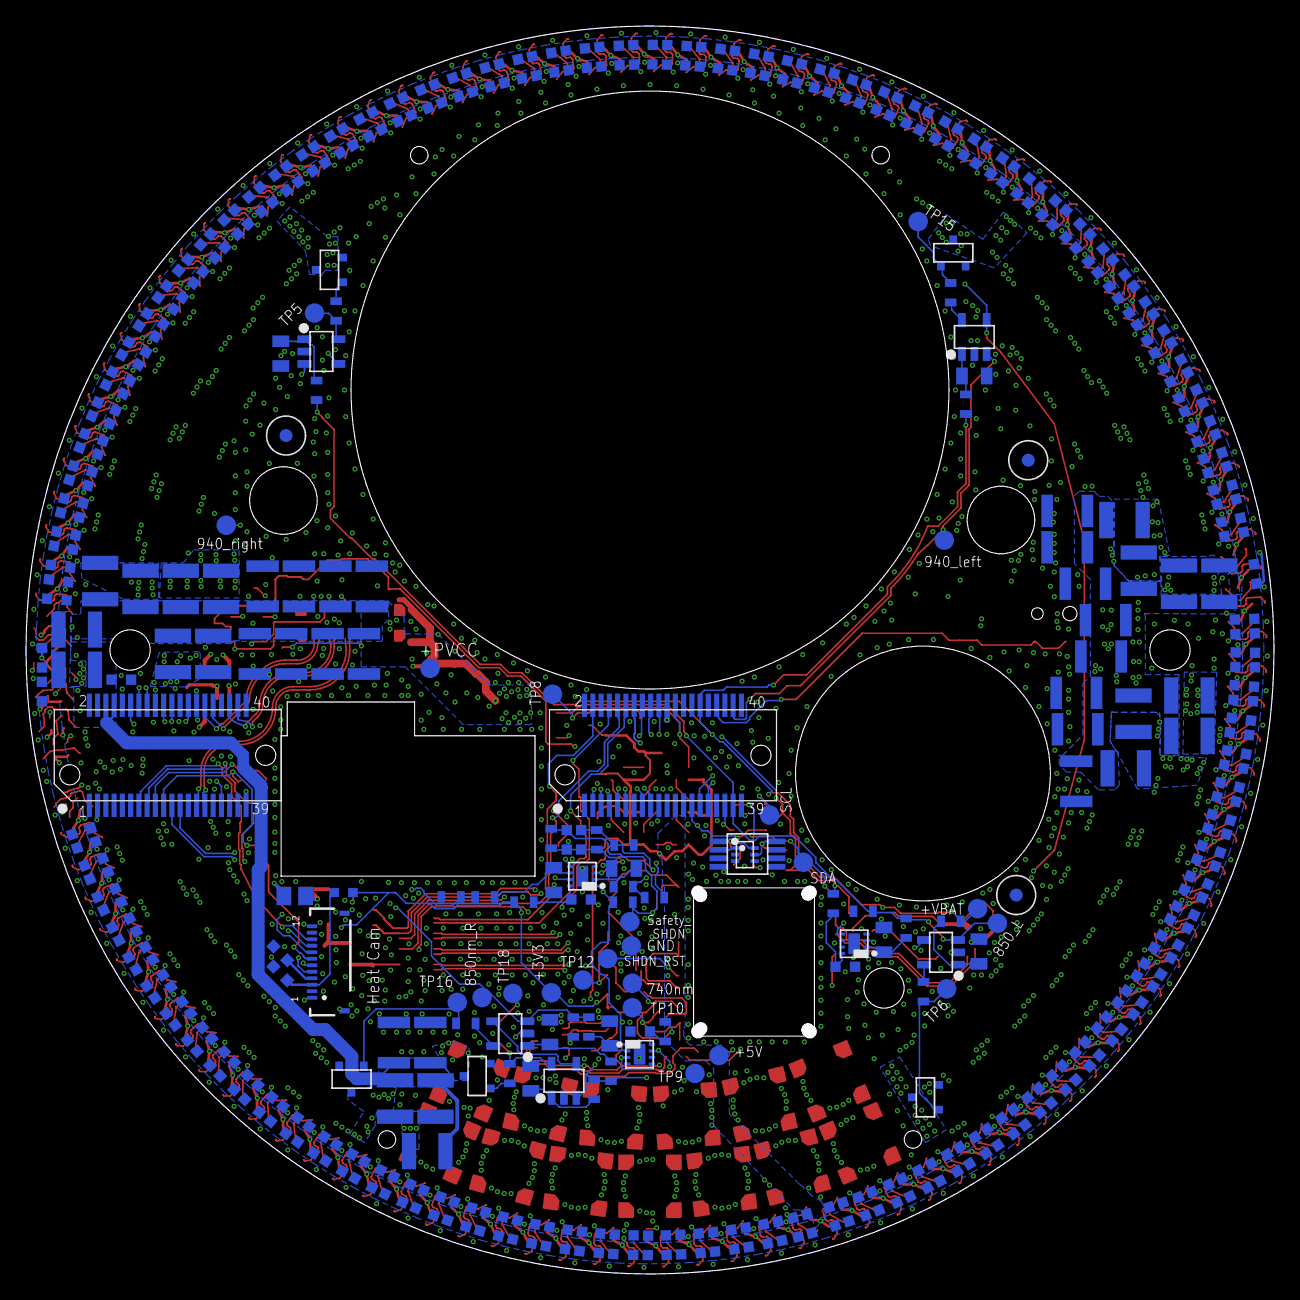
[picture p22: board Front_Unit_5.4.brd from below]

Board: 4 copper layers, 96.0 x 96.0 mm, 723 parts (335 on the bottom side), 415 nets.

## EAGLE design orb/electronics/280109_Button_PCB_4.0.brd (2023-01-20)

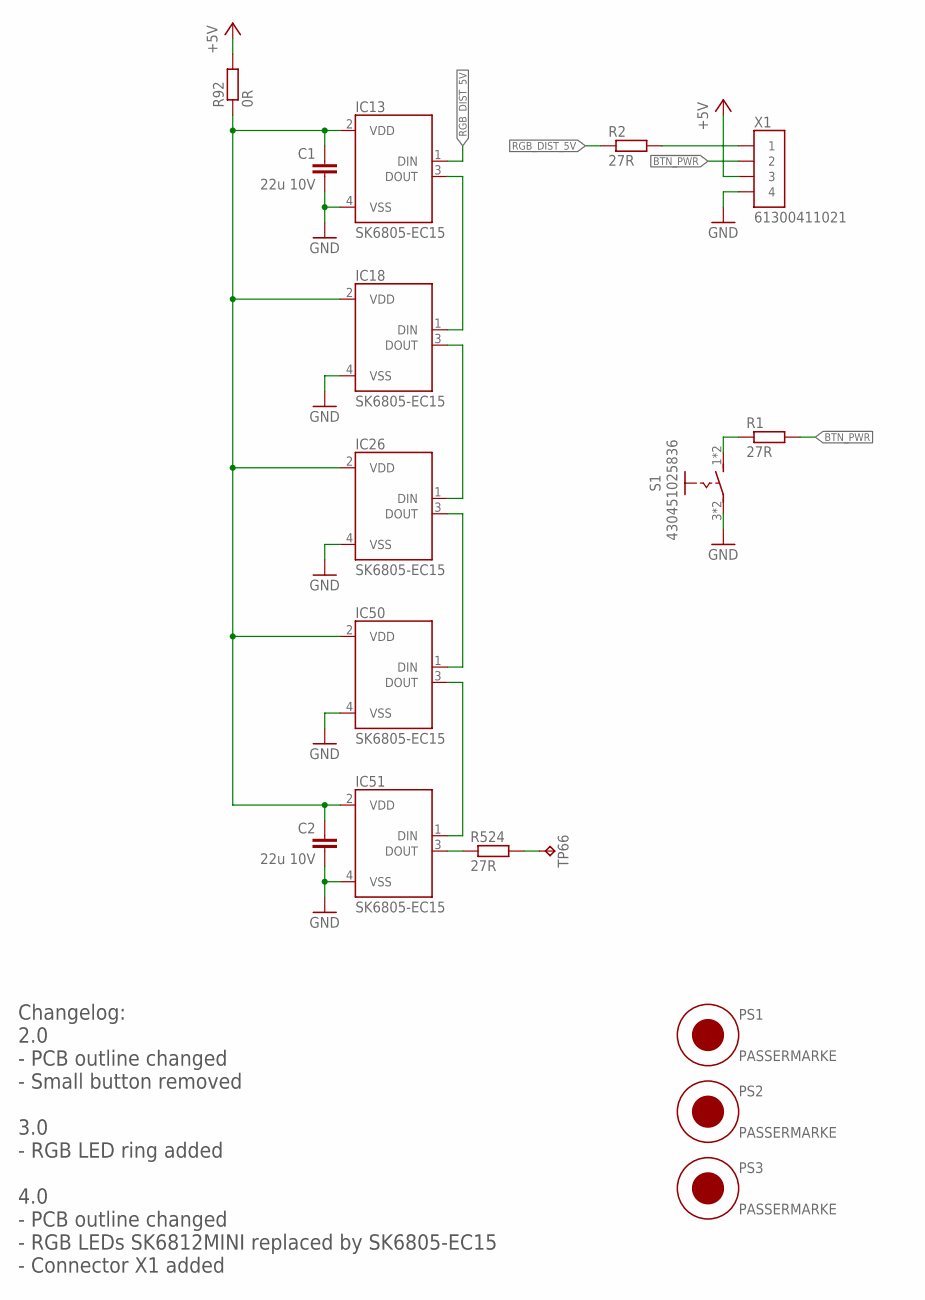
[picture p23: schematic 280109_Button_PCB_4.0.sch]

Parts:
C1, C2: 22u 10V; C0805; VOLTAGE 10.0 V
IC13, IC18, IC26, IC50, IC51: SK6805-EC15; SK6805-EC_IPIXEL
PS1, PS2, PS3: PASSERMARKE
R1, R2, R524: 27R; R0603
R92: 0R; R0603
S1: 430451025836; 430451025836_WUERTH
TP66: TESTPOINT_VIA_ROUND_0.8MM; TESTVIA_ROUND_0.8MM
X1: 61300411021; 61300411021_WUERTH

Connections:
!BTN_PWR: R1.2, X1.2
+5V: R92.2, X1.3
GND: C1.2, C2.2, IC13.4 (VSS), IC18.4 (VSS), IC26.4 (VSS), IC50.4 (VSS), IC51.4 (VSS), S1.3, S1.4, X1.4
unnamed: R1.1, S1.1 (S), S1.2 (S)
unnamed: R2.2, X1.1
unnamed: R524.2, TP66.P$1
unnamed: C1.1, C2.1, IC13.2 (VDD), IC18.2 (VDD), IC26.2 (VDD), IC50.2 (VDD), IC51.2 (VDD), R92.1
unnamed: IC51.3 (DOUT), R524.1
unnamed: IC50.3 (DOUT), IC51.1 (DIN)
unnamed: IC26.3 (DOUT), IC50.1 (DIN)
unnamed: IC18.3 (DOUT), IC26.1 (DIN)
unnamed: IC13.3 (DOUT), IC18.1 (DIN)
RGB_DIST_5V: IC13.1 (DIN), R2.1

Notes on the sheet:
Changelog: 2.0 - PCB outline changed - Small button removed 3.0 - RGB LED ring added 4.0 - PCB outline changed - RGB LEDs SK6812MINI replaced by SK6805-EC15 - Connector X1 added

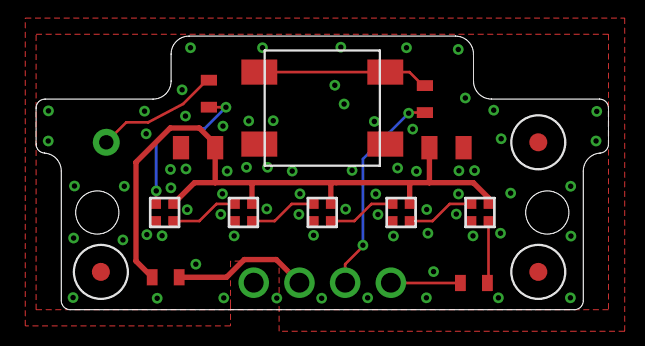
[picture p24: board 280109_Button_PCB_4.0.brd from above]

Board: 2 copper layers, 31.8 x 15.2 mm, 17 parts (1 on the bottom side), 13 nets.

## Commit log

2023-01-27 updated engineering files
    [20220403-TLA-PEARL-ORB-EVT-EVT.C-Part-List.csv, 20220403-TLA-PEARL-ORB-EVT-EVT.E-Part-List.csv, 280112_Battery_Connector_UEBK-30257_1.0.brd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]
2023-06-01 Fix typo
    Changed "including" to "include" in one instance, which is the right form in this case.
2024-03-14 updated electronics, BOM and descriptions to latest hardware design
    [20220403-TLA-PEARL-ORB-EVT-EVT.E-Part-List.csv, 20220403-TLA-RUBY-BATTERY-EVT-EVT.C-Part-List.csv, 20240313-TLA-PEARL-ORB-EVT.F1.csv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]
2024-03-22 updated STEP files for battery and orb
2024-03-22 review and correction BOM
    [20240313-TLA-PEARL-ORB-EVT.F1.csv]
2026-10-19 INFRA-7622: use CloudFront for hardware CAD downloads
